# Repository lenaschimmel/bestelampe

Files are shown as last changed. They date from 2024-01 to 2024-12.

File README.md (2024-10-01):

<!--
SPDX-FileCopyrightText: 2024 Lena Schimmel <mail@lenaschimmel.de>
SPDX-License-Identifier: CC-BY-SA-4.0

[besteLampe!](https://lenaschimmel.de/besteLampe!) © 2024 by [Lena Schimmel](mailto:mail@lenaschimmel.de) is licensed under [CC BY-SA 4.0](http://creativecommons.org/licenses/by-sa/4.0/?ref=chooser-v1)
-->

<!-- *Apart from this README, most documentation and notes are in German. If this project becomes more than a proof-of-concept, all important parts the documentation will be translated to English. The name will remain German, as it should be understandable to English speakers as well.* -->

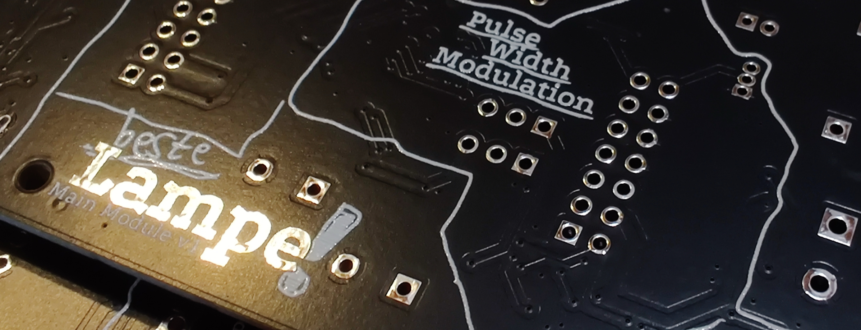
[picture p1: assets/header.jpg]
Header image with PCB closeup


## besteLampe!
**Most lamps suck. This is an open source hardware and software project to create not only a better lamp, but the best lamp(s). Or *"besteLampe(n)!"* as we say in German.**

Of course, there are **many** kinds of lamps, and for some use cases, better alternatives exist. This one is created with two main use cases in mind:
 - indoor lamp for general room lighting and as a sunrise alarm clock 
 - outdoor lamp in front of apartments (called ABL, see below)

The first case involves more direct, manual control of a single lamp, and the second case is more about automatic control (time based, responding to movement, linked with nearby lamps). Anyway, the lamp in each use case will sometimes be operated *just like in the other use case*, so both have mostly the same requirements, just with different priorities.

## Structure of this repository
This project started out with a lot of experimental modules, see [experiments.md](./experiments.md) for information about those.

Current development is focused on the Access Balcony Lamp (ABL), see [hardware/abl](./hardware/abl/) for more information.

Development on indoor lamps may continue once the ABL is finished.

The repository is currently undegoing some restructuring to make it clearer which parts are outdated, active or for future applications.

## What makes ~~a good~~ the best lamp?
These are the design goals of *besteLampe!* 

 - **Free and Open** • open hardware, open software, open protocols
 - **State-of-the-art dimming** • Flicker free, smooth dimming, extremely wide contrast ratio (a.k.a "dim to zero"), independent dimming of color and brightness. (See  ["The problem with driving LEDs with PWM"](https://codeinsecurity.wordpress.com/2023/07/17/the-problem-with-driving-leds-with-pwm/) by Graham to understand what's so hard about that.)
 - **Premium color control** • Use as many color channels as needed to extend the color gamut and achieve good color quality in a reasonable range of colors. (See [the wiki page "Colors"](https://github.com/lenaschimmel/bestelampe/wiki/Colors) for the complexities involved)
 - **Smart, but not smart-ass** • Offers a wide range of wireless connection option, but is also a good, usable device when it's only connection is to the power grid.
 - **Cost efficient** • Should be less expensive than off-the-shelf smart lamps, even if they lack most of its features.
 - **Versatile** • Can be used for many different applications.
 - **Modular** • Provide many features, but not absurdly many, on the base module.
 - **Mains operated, but low voltage DC** • Don't mess with deadly AC.
 - **Power efficiency** • mostly by dimming and switching off.
 - **React to motion and presence** • IR-sensors can only detect motion, so a microwave- or mmwave-sensor must be supported.
 - **Hackable** • Over the air update, flash software and view logs via USB or UART. Pins for future expansions.
 - **Insect friendly** • Reduce the amount of light at night and offer insect friendly spectrum options.
 - **Sleep cycle aware** • Dim lights and avoid blue wavelength at night.
 - **Durable** • Should be usable for decades. Possibility to repair or replace individual parts or modules. Monitor it's own state and send warnings.
 - **Reliable** • Handle outages gracefully, no matter if power outage, network problems or minor component defects.
 - **Fun** • When all the important features are done, add some nice extras. Blinkenlighs-like light shows? UV light? Light based games? Let's do it!

## Not-to-do-list
 - Battery charging, photovoltaic, etc.
 - Addressable LEDs. There is a pin called "Neopixel" but that's not really a design priority, since most addressable LEDs lack in light quality (dimming steps, CRI, flicker)

## License
The besteLampe! is open hardware: 

- The hardware design is licensed under [CERN-OHL-S v2](https://ohwr.org/cern_ohl_s_v2.txt) or any later version.
- The software is licensed under [GNU General Public Licence v3.0](https://creativecommons.org/licenses/by-sa/4.0/legalcode) or later
- The documentation is licensed under [Creative Commons Attribution Share Alike 4.0 International](https://creativecommons.org/licenses/by-sa/4.0/)



See the [license](./license) directory for more details.

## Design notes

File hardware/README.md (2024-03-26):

<!--
SPDX-FileCopyrightText: 2024 Lena Schimmel <mail@lenaschimmel.de>
SPDX-License-Identifier: CC-BY-SA-4.0

[besteLampe!](https://lenaschimmel.de/besteLampe!) © 2024 by [Lena Schimmel](mailto:mail@lenaschimmel.de) is licensed under [CC BY-SA 4.0](http://creativecommons.org/licenses/by-sa/4.0/?ref=chooser-v1)
-->

## Hardware components
 - Hardware
   - **[Main Modules](/hardware/mainmodule/)** • Control board with power supply, micro controller, 6-channel PWM (pulse width modulation) dimmer and many ports.
   - **Extension Modules** • Additional simultaneous wireless protocols, 16 additional PWM channels. Not started yet.
   - **LED Modules** • Stuff that actually emits light. Current focus of hardware development, which might have large impact on the future development of the Main Module as well.
   - **Enclosure** • To hold the electronics together, protect it from the environment, and guide the light.
   - **Reflectors** • Some experiments with 3d-printed reflectors.

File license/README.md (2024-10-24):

<!--
SPDX-FileCopyrightText: 2024 Lena Schimmel <mail@lenaschimmel.de>
SPDX-License-Identifier: CC-BY-SA-4.0

[besteLampe!](https://lenaschimmel.de/besteLampe!) © 2024 by [Lena Schimmel](mailto:mail@lenaschimmel.de) is licensed under [CC BY-SA 4.0](http://creativecommons.org/licenses/by-sa/4.0/?ref=chooser-v1)
-->

## License
The besteLampe! is open hardware and tries to follow the [Best Practices for Open Source Hardware 1.0](https://www.oshwa.org/sharing-best-practices/) from the Open Source Hardware Association (OSHWA).

- The hardware design is licensed under [CERN-OHL-S v2](https://ohwr.org/cern_ohl_s_v2.txt) or any later version.
- The software is licensed under [GNU General Public Licence v3.0](https://creativecommons.org/licenses/by-sa/4.0/legalcode) or later
- The documentation is licensed under [Creative Commons Attribution Share Alike 4.0 International](https://creativecommons.org/licenses/by-sa/4.0/)



All licenses are available in this directory.

## Standard header for hardware design files
### KiCAD
```
(comment 1 "See  https://lenaschimmel.de/besteLampe! for the source and more information")
(comment 2 "This source describes Open Hardware and is licensed under the CERN-OHL-S v2.")
(comment 3 "Copyright 2024 Lena Schimmel <mail@lenaschimmel.de>")
(comment 4 "Design for JLCPCB 1-2 Layer Service")
```

### Others
```
SPDX-FileCopyrightText: 2024 Lena Schimmel <mail@lenaschimmel.de>
SPDX-License-Identifier: CERN-OHL-S-2.0+
This source describes Open Hardware and is licensed under the CERN-OHL-S v2.
You may redistribute and modify this source and make products using it under the terms of the CERN-OHL-S v2 ( https://ohwr.org/cern_ohl_s_v2.txt ).
This source is distributed WITHOUT ANY EXPRESS OR IMPLIED WARRANTY, INCLUDING OF MERCHANTABILITY, SATISFACTORY QUALITY AND FITNESS FOR A PARTICULAR PURPOSE. Please see the CERN-OHL-S v2 for applicable conditions.
Source location: https://lenaschimmel.de/besteLampe!
As per CERN-OHL-S v2 section 4, should You produce hardware based on this source, You must where practicable maintain the Source Location visible on the products you make using this Source, specifially:
 - on at least one printed circuit board inside the product
 - on the external case of the product, if that case is not made in a way that makes it obvious how it can be opened, or if you use practical or legal means to prevent or discourage the user from opening the case, or if the product does not contain a suitable printed circuit board to show the Source Location
```

## Standard header for software source files
```
// SPDX-FileCopyrightText: 2024 Lena Schimmel <mail@lenaschimmel.de>
// SPDX-License-Identifier: CERN-OHL-S-2.0+
// This file is part of besteLampe!.
// 
// besteLampe! is free software: you can redistribute it and/or modify it under the
// terms of the GNU General Public License as published by the Free Software Foundation, 
// either version 3 of the License, or (at your option) any later version.
// 
// besteLampe! is distributed in the hope that it will be useful, but WITHOUT ANY WARRANTY; 
// without even the implied warranty of MERCHANTABILITY or FITNESS FOR A PARTICULAR PURPOSE. 
// See the GNU General Public License for more details.
// 
// You should have received a copy of the GNU General Public License along with besteLampe!.
// If not, see <https://www.gnu.org/licenses/>. 
```

## Standard header for documentation files
```
<!--
SPDX-FileCopyrightText: 2024 Lena Schimmel <mail@lenaschimmel.de>
SPDX-License-Identifier: CC-BY-SA-4.0

[besteLampe!](https://lenaschimmel.de/besteLampe!) © 2024 by [Lena Schimmel](mailto:mail@lenaschimmel.de) is licensed under [CC BY-SA 4.0](http://creativecommons.org/licenses/by-sa/4.0/?ref=chooser-v1)
-->
```

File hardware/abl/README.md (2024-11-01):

<!--
SPDX-FileCopyrightText: 2024 Lena Schimmel <mail@lenaschimmel.de>
SPDX-License-Identifier: CC-BY-SA-4.0

[besteLampe!](https://lenaschimmel.de/besteLampe!) © 2024 by [Lena Schimmel](mailto:mail@lenaschimmel.de) is licensed under [CC BY-SA 4.0](http://creativecommons.org/licenses/by-sa/4.0/?ref=chooser-v1)
-->
## besteLampe! Access Balcony Lamp (ABL)
The Access Balcony Lamp (short ABL, German "Laubengang-Lampe") will be the first device of the besteLampe! series to actually be manufactured.

## Component overview
It consists of these parts:
 - Power Module
   - [Power PCB](./power/)
 - Lamp Module 
   - [LED PCB](./LED_Module_E/)
   - [Controller PCB](./controller/)
 - Connectors between the main PCBs
   - [Rigid connector](./rigid_connector/)
   - [Flex connector](./flex_connector/)
 - Enclosure
   - Not yet online

Additional ressouces:
 - Tools
   - [LED heatplate](./LED_heatplate/)

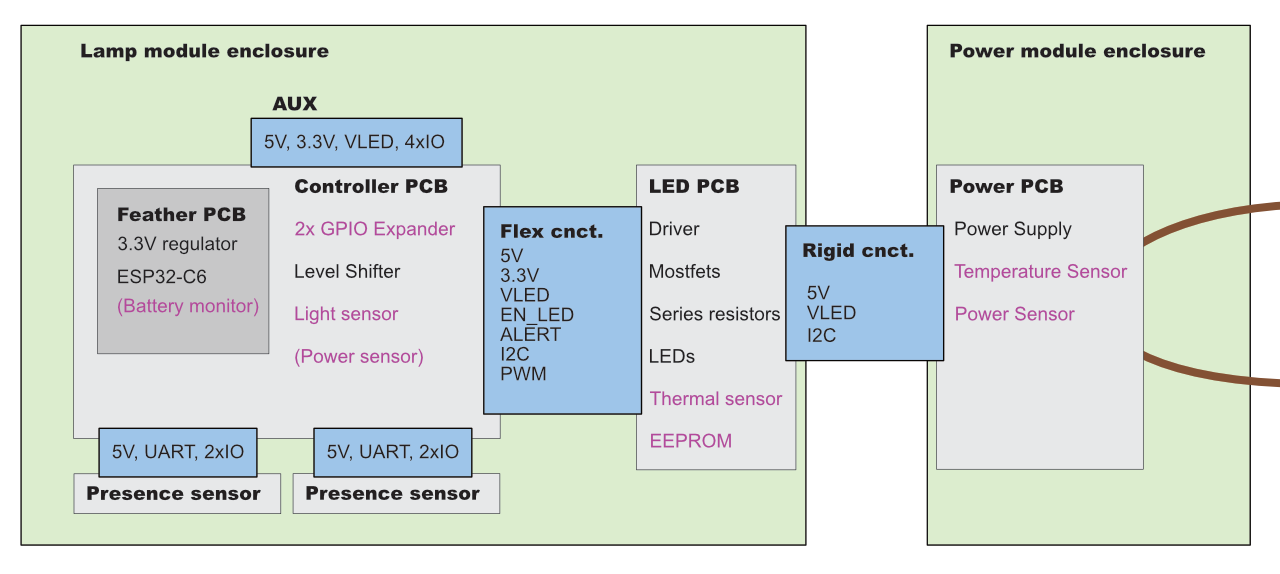
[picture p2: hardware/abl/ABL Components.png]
Simplified diagram of modules and components


## Voltages
The complete system has three or four different voltages / power rails:
 - **230V AC** Input voltage (power modules can be daisy-chained)
 - **5V** Output by the power module and fed through to all other modules. When the controller module is connected via USB-C, it can also source 5V from there and feed it to other components.
 - **3.3V** Supply voltage for several components. The feather module generates this from its 5V input and shares it with most other components. The power module has its own 5V-to-3.3V conversion (which is a bit strange, but probably ok and not worth changing).
 - **VLED** The voltage to drive the LEDs. This is the most significant part of the systems power consumption.

Ideally, the LEDs would be driven with 4V, but since I did not find any power supplies with that voltage, they are currently driven with 5V. For historic reasons, the net `VLED` might still be called `4V` in some places.

Event though the nets `VLED` and `5V` currently carry the same voltage from the same source, they are separate nets in theory. If we manage to find a good 4V power supply, we could create a new power module, and the other modules and connectors should just work with that. The series resistors for the LEDs should probably be replaces as well.

The README for most modules will also have complementing information about available voltages.

## I2C addresses
All modules share a common I2C bus. In the above diagram, the I2C components are highlighted by violet text.

Most devices support multiple addresses, which are selected via address pins. Some of them recognize 4 states per pin: high, low, SDA and SDC. Using static high and low for address selection seems to be more robust.

The INA219 power sensor on the power board serves an additional purpose: the address it reacts to indicates if a 20W or 30W power supply has been installed in the power module.

 - Power Module
    - 64 = 1000000: INA219 (in case of 20W power supply)
    - 65 = 1000001: INA219 (in case of 30W power supply)
    - 82 = 1010010: 24AA025UID (Starting with v1.2, may also trigger 24AA02UID on LED Module v2.0)
    - 79 = 1001111: TMP1075
 - LED Module
    - 75 = 1001011: TMP1075
    - 81 = 1010001: 24AA025UID (Starting with v2.1)
    - 87 = 1010111: 24AA02UID (Will react to any address from 80 to 87, only on v2.0)
 - Controller Module
    - 16 = 0010000: VEML6040
    - 32 = 0100000: TCA6408a (3.3V, starting with v1.1)
    - 33 = 0100001: TCA6408a (5V, starting with v1.1)
    - 67 = 1000011: FLX6408 (3.3V, only in v1.0)
    - 68 = 1000100: FLX6408 (5V, , only in v1.0 - see warning in [controller/README.md](controller/README.md))
    - 69 = 1000101: INA219
 - Feather
    - 54 = 0110110:	Battery monitor (Adafruit ESP-C6)

## Rendering
Artistic rendering showing the inside and outside of the ABL at the same time:

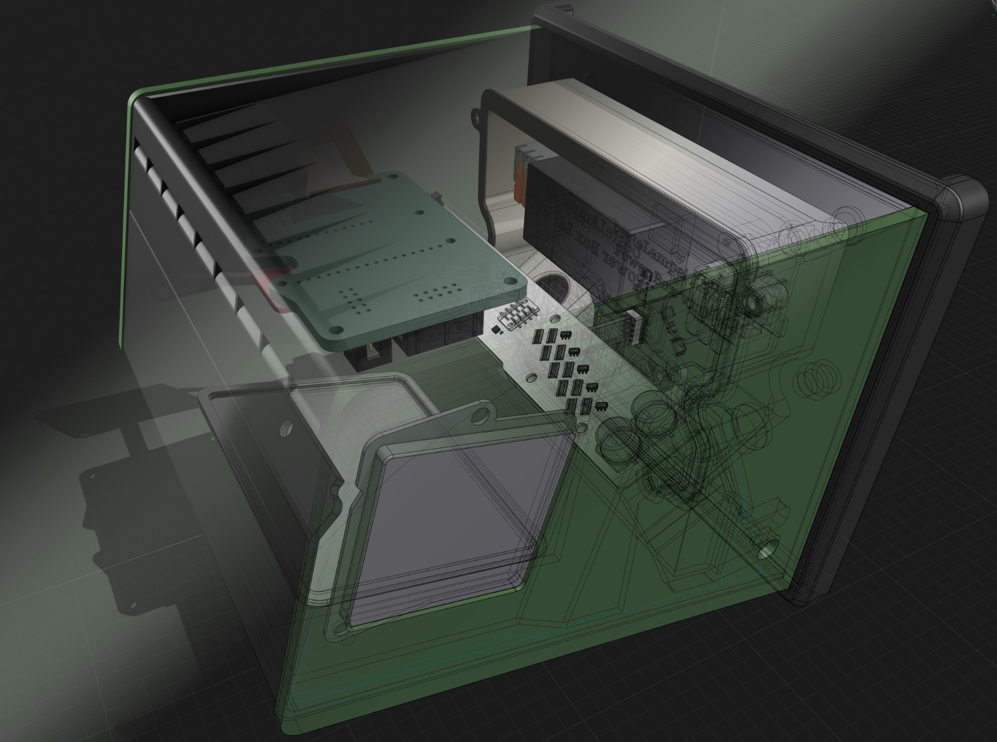
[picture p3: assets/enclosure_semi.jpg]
Image as described above


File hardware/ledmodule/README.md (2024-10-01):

<!--
SPDX-FileCopyrightText: 2024 Lena Schimmel <mail@lenaschimmel.de>
SPDX-License-Identifier: CC-BY-SA-4.0

[besteLampe!](https://lenaschimmel.de/besteLampe!) © 2024 by [Lena Schimmel](mailto:mail@lenaschimmel.de) is licensed under [CC BY-SA 4.0](http://creativecommons.org/licenses/by-sa/4.0/?ref=chooser-v1)
-->

## v1 LED modules
The besteLampe! main module v1 introduced a 14-pin connector for LED modules. 

A very basic module would only have to use two of those Pins: One of the six PWM channel pins, and the 24V pin (5V would also work, but is less efficient in most cases).

More complex modules may have up to six color channels, and may contain one more temperature sensors. They can also contain addressable LEDs, though that is not recommended for the main lighting.

 * Module A and A2 use 6 to 21 mid-power LEDs for each of its six color channels. They are driven with 24V and current-limmiting resistors, so they are directly compatible with Main Module v1.
 * Module B is / was a concept for a slim, quarter-circle module. It's not clear if it will be continued, or made obsolete by Module C.

## Post-v1 modules
Later I experimented a lot with different LEDs, reflectors, lenses, PWM generators, constant-current drivers, etc. These experiments cannot be directly connected to a v1 main module, since they don't have a compatible 14-pin connector.

 * Module C is a testing module for a novel approach with 1 to 3 high-power LEDs per channel, and needs to be driven by a PWM-capable constand-current driver that does not yet exist. Compatibility with Main Module v1 is still unclear. It was mostly tested with low currents (60mA per LED) and worked very vell, but high-current testing is still needed.
 * Module D is a failed attempt. Do not use.
 * Module E is a heavily modified version of Module D, which (hopefully) works better.
     * Module E adaptor, which lets you connect an ESP32-C6-DevKit-C1 to the Module E V1.0 easily
     * Module E was moved to [ABL](../abl/LED_Module_E/) when it was bumped to Version 2.0 and is no longer compatible with the Adaptor.

It's still unclear how the future connector between a main module and LED module(s) will look like...

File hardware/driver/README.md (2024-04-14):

## Driver Modules
Some LEDs are better driven by constant current drivers (CCDs) than by simple MOSFETs and series resistors. See ["Driving LEDs" in the Wiki](https://github.com/lenaschimmel/bestelampe/wiki/Driving-LEDs) for more background on this.

There are multiple Chips which integrate much of the complexity of such drivers, but all of those ICs need specific peripherals around them to actually work. If paired with the correct peripherals, they should work in a very similar way, so that they could be exchanged for one another.

For low-power CCDs like the TLC59711, breakout-boards are available. But for high-power CCDs, no such breakout-boards existed. There were only evaluation-boards, which are 10 times bigger and 10 times more expensive than a breakout-board.

In this directory, I try to add such breakout-boards with a common footprint and pin configuration:

- Driver Module X - an empty template for actual modules
- Driver Module A - for the Allegro A6211

Other drivers that might get a driver module:
- Texas Instruments TPS92200
- Diodes Inc. AL8860
- _If you know similar drivers, let me know!_

I've looked at theses ones as well, but it's unlikely I will make a driver module for them:
- WLMDU9456001JT / 172946001 / MagI3C Power Module (only 450mA and very expesive)
- STM ALED600 (rather expensive and needs many peripherals)

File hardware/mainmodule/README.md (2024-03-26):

<!--
SPDX-FileCopyrightText: 2024 Lena Schimmel <mail@lenaschimmel.de>
SPDX-License-Identifier: CC-BY-SA-4.0

[besteLampe!](https://lenaschimmel.de/besteLampe!) © 2024 by [Lena Schimmel](mailto:mail@lenaschimmel.de) is licensed under [CC BY-SA 4.0](http://creativecommons.org/licenses/by-sa/4.0/?ref=chooser-v1)
-->

# Main module 

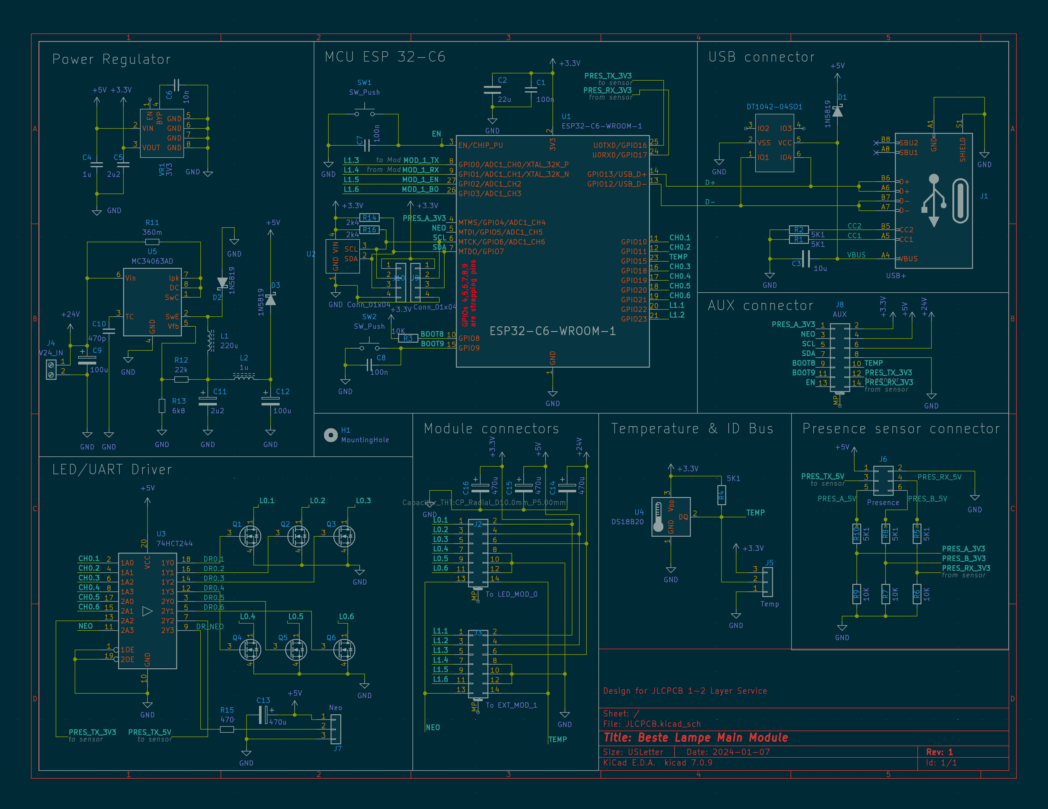
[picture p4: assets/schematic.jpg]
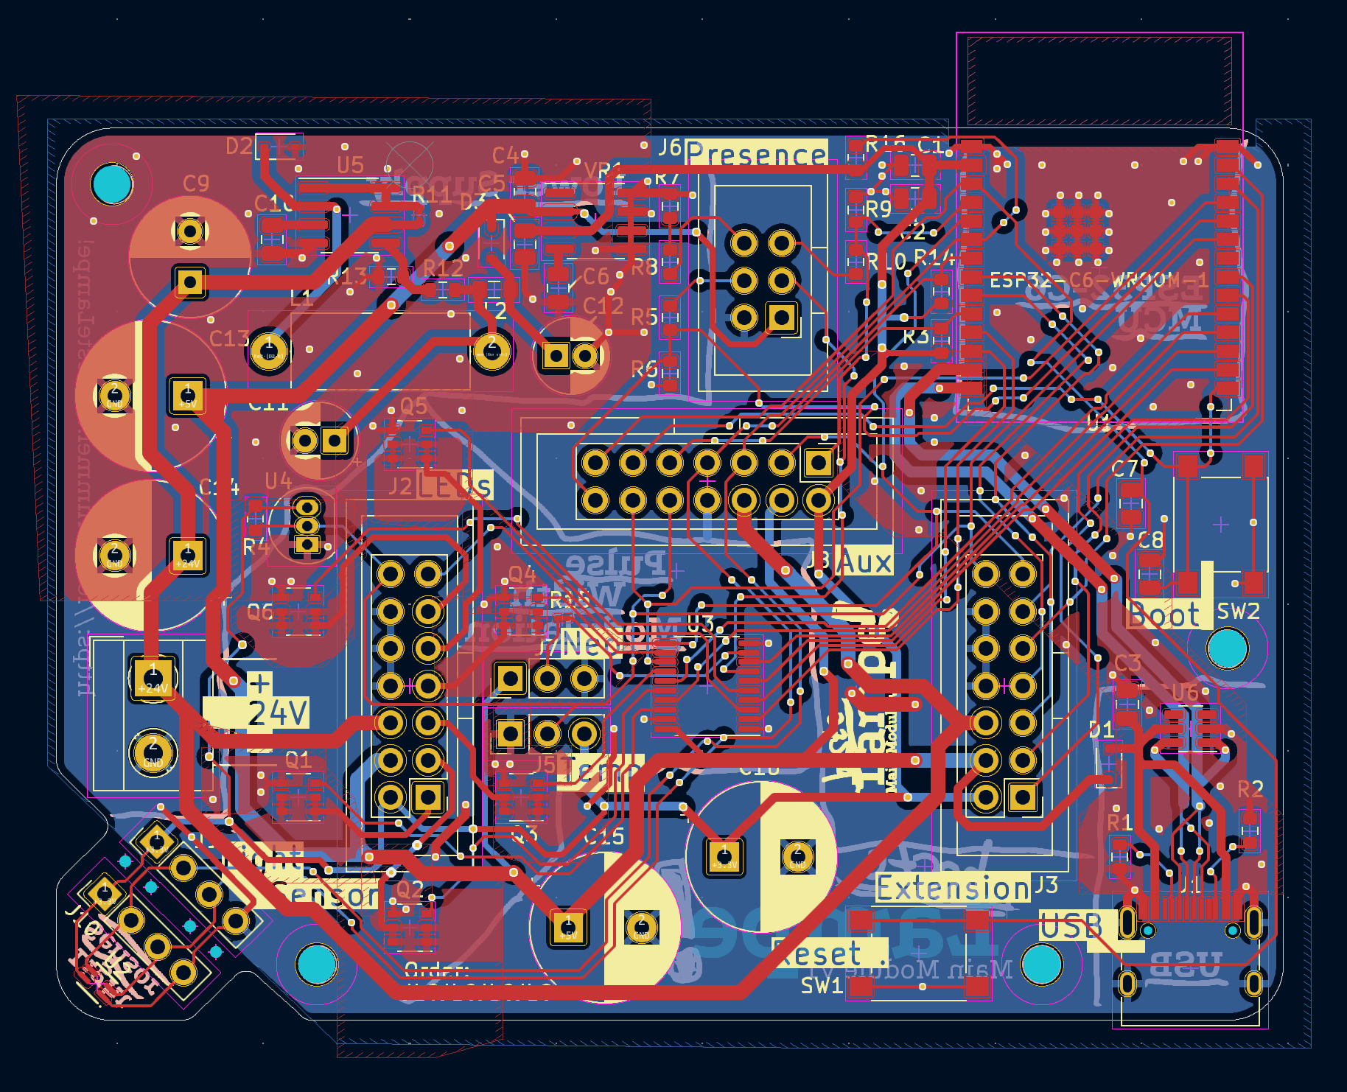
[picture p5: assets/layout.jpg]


## Hardware features / components
- Standard 2-layer PCB
- ESP32-C6 MCU
- Supports four wireless protocols (only one at a time, except Wifi and Bluetooh which can co-exist)
  - Wifi
  - Bluetooth
  - Zigbee
  - Thread
- 6 MOSFET-driven PWM channels with flexible frequency / bit depth
  - e.g. 13 bits = 8192 levels at 5000 Hz
  - or 15 bits = 32,768 levels at 1250 Hz
  - optional 4 bit temporal dithering, increasing the levels by a factor of 16 without reducing the frequency
- Connectors
	- J1: multi-purpose USB-C connector
		- flash new firmware, even when current firmware is broken
		- view logs
		- power the board (Powers everything but LEDs. You may combine USB power and DC power, and switch between both at runtime)
	- J2: LED module. Supports temperature sensor(s) on the LED module.
	    - **Attention: Pins 8, 10 and 12 are GND. In future versions, only pin 12 will remain GND. Pins 8 and 10 will be +24V.**
	- J3: Extension module. Usually contains a secondary MCU and additional LEDs and/or hardware.
	- J4: Power. DC Input 6V to 24V.
		- Must be the same as LED voltage.
		- Generates 5V (buck converter) and 3,3V (linear voltage regulator) for internal and external peripherals.
	- J5: Temp. Attach additional temperature sensor(s) here and/or on the LED module and/or extension module.
	- J6: Presence sensor. Made for seed studio model MR24HPC1, may work with others.
	    - Provided 5V power to the sensor.
		- TX is shifted up from 3,3V to 5V
		- RX, A and B are shifted down form 5V to 3,3V
		- B is not connected to the MCU
	- J7: Neopixel. You can connect addressable LEDs here. Only 5V supported on this connector. Modules on J2 and J3 also get the control signal, and get 24V to power LEDs.
	- J8: AUX. Used for debugging, testing, etc.
	- J9 and J10: Light sensor. The VEML6040 sensor is directly connected on the PCB, but you could break off or cut off the part with the sensor and use these pins to connect it over wire.
- 1-wire bus for temperature sensors and other devices
	- onboard 12 bit temperature sensor between Mosfet and capacitors
	- bus is also connected to J2, J3, J5 and J8

## Cost
I've ordered 10 PCBs from JLCPCB, with SMD components included and soldered, but without any through-hole components. I payed about 100 Euro incl. tax and shipping, so around 10 Euros per PCB. This does not include the ESP32-C6 (3.60 Euro) because they didn't have it in stock, nor the VEML6040 Light sensor (0.90 Euro) because I forgot to place it. So the actual price would be 14.50 Euro per board.

When ordering 100 pieces, and with some very minor tweaks in v1.1 to reduce the assembly fees, price per PCB incl. SMD assembly will drop to 8.10 Euro incl. ESP and light sensor.

The through hole components are 4.30 Euro per board and will drop top 2.70 for v1.1.

So the full v1.1 board will be around 10.80 Euro.

## Known problems for v1
_Should be converted into issues soon, but it's quicker to just list them here._

### High severity
_No known fix_

* The inductor of the 5V buck converter makes an audible noise, especially when the presence sensor is connected

### Medium severity
_Prevent the board from working, but can easily be fixed manually_

* Wrong footprint for R11 and R15, so they are not assembled. Because they are not really needed, you can bridge them with a drop of solder.
* Pin 1 of VR1 (Enable of the 3.3V voltage regulator) needs to be connected to 5V. You can place a very short wire or even a drop of of solder over to Pin 2.
* Pin 3 of the ESP (Enable) module needs a pull up resistor. You can hand-solder one to the bottom of J8, or instead of J8 if you don't need the connector.
* Light sensor is no placed, and it's unknown if it would work if placed

### Low severiy
_Would be nice to fix these, but it's ok as it is_

* The antenna of the ESP extends over the rectangular board footprint. That was a deliberate design choice, but I regret it.
* Mounting holes are too small for M3 screws.
* An additional mounting hole at the top right would be nice.
* USB data lines are length-matched and work just fine (it's just USB 2.0), but violate many rules:
   * not impedance-controlled (I tried, but used totally wrong numbers)
   * opposite ground plane is not continous
   * four vias when it could be done with zero or two
* Thick wires have tiny vias
* Net `Pres_B` of the presence sensor is shifted down to 3.3V but not connected to the ESP or anything else
* Would be nice to have some small LEDs on board
	* Power LEDs that light up as long as there is 24V, 5V and 3,3V (should be very dim)
	* 1 LED per PWM channel to test it without an LED module attached (common +24V could be switched with a jumper)
* It would also be nice to support USB Power Delivery, so that the LEDs could light up when only USB is connected, for easier development. PD does not support 24V, only 20V, but the LEDs that I tested are ok with that.
* use an SMD version of the temperature sensor because it's much cheaper

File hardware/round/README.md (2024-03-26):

<!--
SPDX-FileCopyrightText: 2024 Lena Schimmel <mail@lenaschimmel.de>
SPDX-License-Identifier: CC-BY-SA-4.0

[besteLampe!](https://lenaschimmel.de/besteLampe!) © 2024 by [Lena Schimmel](mailto:mail@lenaschimmel.de) is licensed under [CC BY-SA 4.0](http://creativecommons.org/licenses/by-sa/4.0/?ref=chooser-v1)
-->

## Round lamp enclosure
This is a prototype of a round, wall-mounted lamp enclosure, based on a cheap transparent flower pot I found at the local hardware store.

It's intended for an *extended setup* (see [the "Price" section in the main readme](/README.md#price)), so it will have four groups of six color channels. That makes it possible to control the brightness and color for each direction separately. The current iteration prioritizes the diffusor for very smooth transitions between the four sections, and the light emission is undirected.

Instead of LED modules with custom PCBs, I'm using short LED strips which can be bent in one dimension only.

There is also a short ring of addressable LEDs that illuminate the front plate. You can insert a mask here to display e.g. a house number, short word or small graphic, and tint it in colorful animated gradients.

**Everything in this directory is very messy and work in progress - you are not (yet) suppose to understand the files and how to assemble this lamp.**

## Principle and Prototype
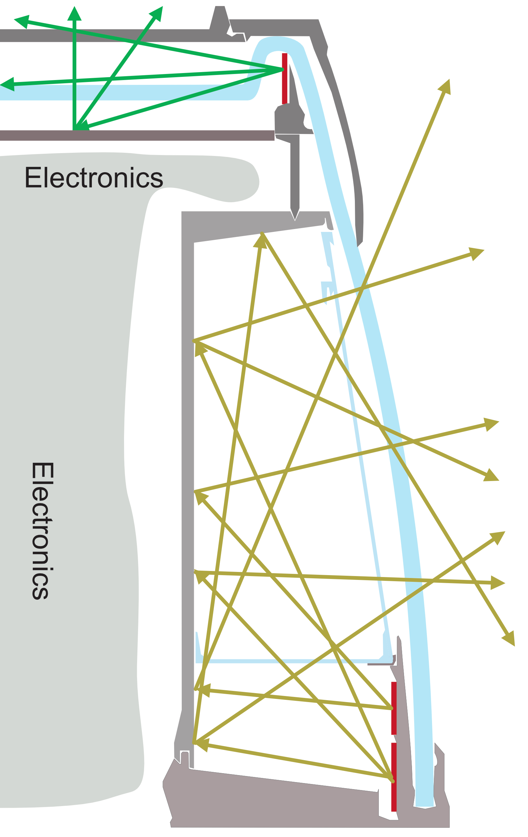
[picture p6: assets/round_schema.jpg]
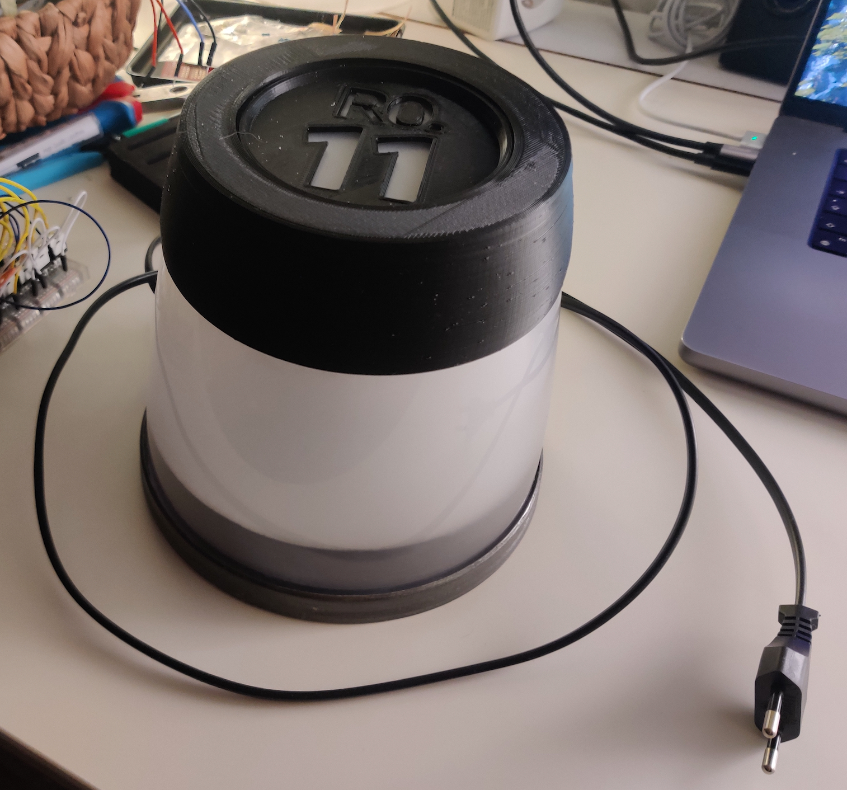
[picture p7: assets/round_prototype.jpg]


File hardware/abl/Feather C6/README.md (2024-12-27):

## Adaptation of Adafruit ESP32-C6 Feather - STEMMA QT PCB
### Adaptation
This PCB design is based on the [Adafruit ESP32-C6 Feather - STEMMA QT PCB](https://github.com/adafruit/Adafruit-ESP32-C6-Feather-PCB).

At the beginning, it was only a port of the EagleCAD schematic and board layout to KiCad.

With time, it will deviate further from the original design, with these primary development goals:
 - [x] Better signal integrity and EMI, by using:
   - [x] Proper ground planes, using 4 instead of 2 layers
   - [x] More ground pins
 - [ ] Reduced production cost by removing some components
   - [ ] LiPo battery charger / monitor and connector
   - [ ] NeoPixel
 - [ ] Changes to the power pins to better support different directions of power distribution (from USB to Wing, or from the Wing)

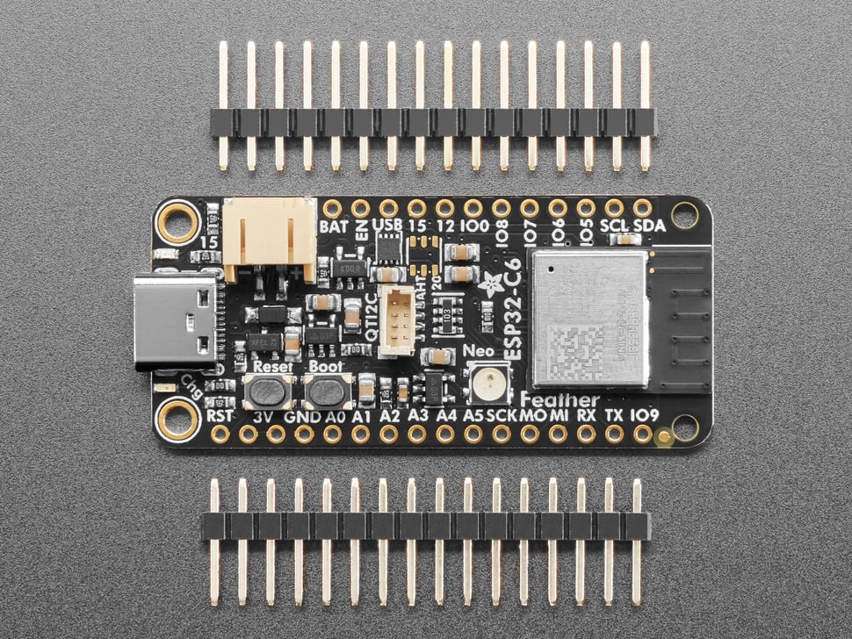
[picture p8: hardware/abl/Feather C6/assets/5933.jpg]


See the [original Version in the Adafruit shop](https://www.adafruit.com/product/5933)

### Description
_Unchanged from the original repository_

The ESP32-C6 is Espressif’s first Wi-Fi 6 SoC integrating 2.4 GHz Wi-Fi 6, Bluetooth 5 (LE) and the 802.15.4 protocol. It brings the goodness you know from the low-cost C3 series and improves it with Zigbee/802.15.4 at 2.4Ghz. That means it could make for great Matter development hardware!

We took our Feather ESP32-S2 and swapped out the 'S2 for a C6. Plus some re-routing and here's what we've got: a C6 Feather with lots of GPIO, lipoly charging and monitoring with the MAX17048, NeoPixel, I2C Stemma QT port, and a second low-quiescent LDO for disabling the I2C and NeoPixel when we want ultra-low power usage - as low as 17uA in deep sleep.

One thing to watch for is that, like the C3, the C6 does not have native USB. It does have a 'built in' USB Serial core that can be used for debugging, but it cannot act like a mouse, keyboard, or disk drive. That means if you are running CircuitPython you will need to use WiFi, Bluetooth or WebSerial for transferring files back and forth rather than drag-and-dropping to a drive. Ditto for the bootloader side, this chip cannot run UF2.

Another thing to be aware of, is  the ESP32-C6 does not have as many GPIO as the ESP32-S2 or ESP32-S3, so A2 is the same GPIO pin as IO6 and A3 is the same pin as IO5. However, this gives it the most compatibility with our existing FeatherWings.

### included components (BOM)
| Part Name | Designator | Count  |
|---|---|---|
| KH-2.54FH-1X16P-H8.5  | JP1 | 1 |
| CL21A106KAYNNNE | C1,C2,C6,C7,C8,C9  | 7 |
| 0603WAF5101T5E | R1,R10,R5,R8 | 5 |
| SK34WA | D4 | 1 |
| IN-S63AT5UW | D3 | 1 |
| KH-2.54FH-1X10P-H8.5  | J1,J2 | 2 |
| KH-2.54FH-1X12P-H8.5  | JP3 | 1 |
| KMR211NGLFS | SW1,SW2 | 2 |
| AP2112K-3.3TRG1 | U2 | 1 |
| CL10A105KB8NNNC | C10,C4 | 3 |
| ESP32-C6-MINI-1-N4 | U1 | 1 |
| 0603WAF1003T5E | R12,R6,R7 | 4 |
| USB-TYPE-C-019 | X3 | 1 |
| DMG3415U | Q3 | 1 |

### License
Adafruit invests time and resources providing this open source design, please support Adafruit and open-source hardware by purchasing products from [Adafruit](https://www.adafruit.com)!

Designed by Limor Fried/Ladyada for Adafruit Industries.

Adapted by Lena Schimmel.

Creative Commons Attribution/Share-Alike, all text above must be included in any redistribution. 
See license.txt for additional details.

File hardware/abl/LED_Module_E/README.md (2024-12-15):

<!--
SPDX-FileCopyrightText: 2024 Lena Schimmel <mail@lenaschimmel.de>
SPDX-License-Identifier: CC-BY-SA-4.0

[besteLampe!](https://lenaschimmel.de/besteLampe!) © 2024 by [Lena Schimmel](mailto:mail@lenaschimmel.de) is licensed under [CC BY-SA 4.0](http://creativecommons.org/licenses/by-sa/4.0/?ref=chooser-v1)
-->

## LED Module E + G
The former LED Module E has been split into two separate PCBs:
 - Module E (classic 4--layer PCB with driver logic, MOSFETs and series resistor)
 - Module G (1-layer copper-core PCB with actual LEDs and temperature sensor)

In conjuction, they feature 10 small, high-powered Cree XLamp Element LEDs places close to one another along an edge, and some of the electronics needed to power them.

The split into separate PCBs is very recent, and the files have not yet been completely reorganized. Module G is still in this directory, and its files are still named "LED_Module_E_copper". They will move into their own directory soon.

### Parts on Module E
| Reference | Value | Datasheet | Footprint | Qty  | DNP  | Manufacturer_Part_Number  | LCSC Part #  | Purpose |
|---|---|---|---|---|---|---|---|---|
| C1,C2,C3 | 100nF | ~ | Capacitor_SMD:C_0402_1005Metric | 3 | | CL05B104KO5NNNC | C1525 | Decoupling capacitor |
| C4,C5 | 1000uF | ~ | Capacitor_SMD:CP_Elec_10x7.9 | 2 | | VKME1301C102MV | C487313 | Bulk capacitor |
| J1 | SFW20S-2STE1LF | https://cdn.amphenol-cs.com/media/wysiwyg/files/drawing/10172832.pdf | Own footprints:SFW20S2STE1LF_Own | 1 | | SFW20S-2STE1LF | C3168412 | Flex cable connector |
| J3 | 9159008603906 | https://datasheets.kyocera-avx.com/9159-600.pdf | 9159008603906 | 1 | | 9159008603906 | C22394454 | Rigid board connector |
| Q1,Q2,Q3,Q4,Q5,Q6,Q7,Q8,Q11,Q12 | Si3456DDV | https://www.vishay.com/docs/69075/si3456ddv.pdf | Package_SO:TSOP-6_1.65x3.05mm_P0.95mm  | 10 | | SI3456DDV-T1-BE3 | C6295864 | MOSFET transistor |
| R1,R2,R3,R4,R5,R6,R7,R8,R9,R10,R11,R12,R13,R14,R15,R16,R17,R18,R19,R20  | 200mR | ~ | Resistor_SMD:R_1020_2550Metric | 20 | | RCWE1020R200FKEA | C4000899 | Series resistor |
| R21,R22,R23,R24,R25,R26,R27,R28,R31,R32,R33,R34,R35,R36,R37,R38 | 4700R | ~ | Resistor_SMD:R_0402_1005Metric | 16 | | 0402WGF4701TCE | C25900 | Pullup resistor |
| R40,R41 | 2740R | ~ | Resistor_SMD:R_0603_1608Metric | 2 | | 0603WAF2701T5E | C13167 | Pullup resistor |
| U2 | 74HC245 | http://www.ti.com/lit/gpn/sn74HC245 | Package_SO:TSSOP-20_4.4x6.5mm_P0.65mm  | 1 | | SN74AHCT245PWR | C10910 | Bus transceivers / line driver  |
| U3 | 24AA025E48T-I/OT  | https://www.lcsc.com/datasheet/lcsc_datasheet_1810121540_Microchip-Tech-24AA025E48T-I-OT_C129895.pdf  | Package_TO_SOT_SMD:SOT-23-6 | 1 | | 24AA025E48T-I/OT | C129895 | EEPROM |
| U4 | 74LVC1G32 | http://www.ti.com/lit/sg/scyt129e/scyt129e.pdf | Package_TO_SOT_SMD:SOT-353_SC-70-5 | 1 | | 74LVC1G32SE | C460530 | Logic OR gate |

### Parts on Module G
This module only contains the 10 LEDs and a temperature sensor:
 - 10x CREE XLamp Element G in 8 different colors ([Datasheet](https://www.mouser.de/pdfDocs/XLamp-XE-G.pdf))
 - 1x TMP1075 Temperature sensor ([Datasheet](https://www.ti.com/lit/ds/symlink/tmp1075.pdf))

### Relation to previous LED modules
Version 1 of this module was partly based on the failed [LED Module D](../../ledmodule/LED_Module_D/), but with a lot of changes:

 - larger board
 - re-assinged all components to the three power rails
 - removed the TLC59711 as PWM generator
 - instead 8 separate inputs for PWM signals
 - two of the input signals are duplicated to power 2 LEDs each (but with separate MOSFETs and resistors)
 - more and larger mounting holes
 - improved thermal conductance (more thermal vias, etc.)
 - optimized traces
 - optional pull-ups for the I2C bus
 - solder jumper to directly tie the alert signal of the temperature sensor to the enable input of the driver
 - added test pads
 - added bulk capacitor
 - switched to 100% SMD parts
 - LED voltage can be supplied via USB-C or via two pins of the Pin header (see below)

It was a bit larger than LED module D, but the placement of the LEDs was still the same, which proved to be a good fit for the linear half-bown reflector prototype.

Now this is version 2, which has a very different form factor. It's much larger, and the LED are on the long side instead of the short one.

### VLED
With single LEDs (parallel, in contrast to series / strings), a voltage around 4V would be a good choice for the supply voltage, so that the series resistors don't waste too much energy.

But it's surprisingly difficult to find a good source for 4V if you've got only 230V AC, 5V and 3.3V DC to work with. It seems much more straight-forward to use 5V and adjust the series resistors to it.

The CD74HCT244 needs 4.5 V to 5.5 V to operate, so it already had a 5V rail. The power rail for the LEDs was historically called 4V, and even though it's lablled `VLED` on the silkscreen now, the nets are still called 4V in Kicad. Both rails are still separate, just in case I'll find a good 4V source in the near future.

### Temperature Alert
Usually, the MCU should monitor the temperature via the TMP1075 sensor, and reduce the LED power before they get too hot. Via I2C, the MCU can read the excact temperature value.

The MCU can also set an alert threshold on the sensor, so that it will trigger its ALERT pin when the LEDs get too hot.

As an extra safety measure, the ALERT net can be linked directly to the ENABLE net via the solder jumper JP1. If the MCU has crashed, or for some other reason is not able to react to the rising temperature, this should turn off the LEDs without the MCUs intervention. This feature is untested, and the jumper is open by default.

### EEPROM addressing issue
Version 2.0 of the LED board contained an 24AA02UID, which will react to any address from 80 to 87. This prevents the usage of multiple EEPROMs on one bus. Newer versions of the LED Module and Power Module use individually addressable 24AA02**5**UID (note the slightly different part number). In software, you should first check if an EEPROM on address on 87 is present. If yes, it's on the LED Module and you can't detect / use an EEPROM on the Power Module. If no, there *should* be an EEPROM at 81 on the LED Module, and there *could* be another on on 82 on the Power module.

### Rendering
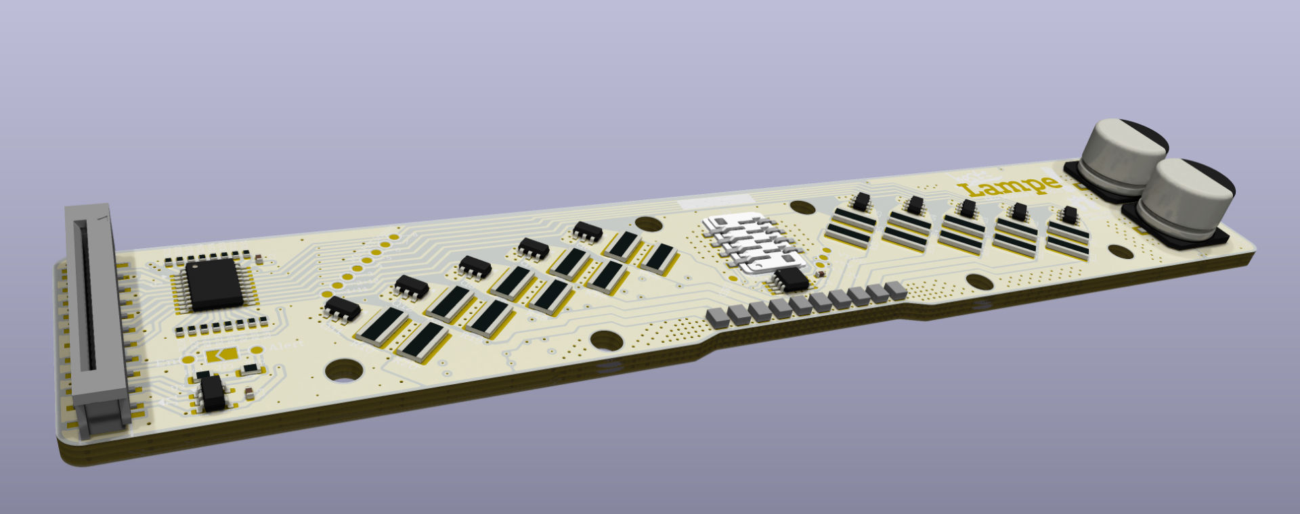
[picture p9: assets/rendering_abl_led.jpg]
KiCad rendering of the PCB, as of 2024-10-24


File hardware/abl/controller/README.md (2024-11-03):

<!--
SPDX-FileCopyrightText: 2024 Lena Schimmel <mail@lenaschimmel.de>
SPDX-License-Identifier: CC-BY-SA-4.0

[besteLampe!](https://lenaschimmel.de/besteLampe!) © 2024 by [Lena Schimmel](mailto:mail@lenaschimmel.de) is licensed under [CC BY-SA 4.0](http://creativecommons.org/licenses/by-sa/4.0/?ref=chooser-v1)
-->
## ABL Controller Module
This module started out as a simple passive adapter to connect an ESP32-C6 to the LED Module and power module, but has become more complex by now.

It contains an RGB light sensor and connects to:
 - up to two human presence sensors
 - optional expansions via
   - I2C (Quiic / Stemma QT connector)
   - additional GPIOs

### Feather MCUs
The socket for the MCU has the [Adafruit Feather](https://learn.adafruit.com/adafruit-feather/overview) formfactor. There are at least three different implementations of the ESP32-C6 in this formfactor, as well as dozens of other MCUs.

The feather spec is strict enough that every kind of Feather *should* be safe to plug in, e.g. fits mechanically and will not damage itself or other modules. The specific pin assignments of feathers are different though, and care has been taken to use the pins in a way that is at least compatible with all three ESP32-C6 feathers:

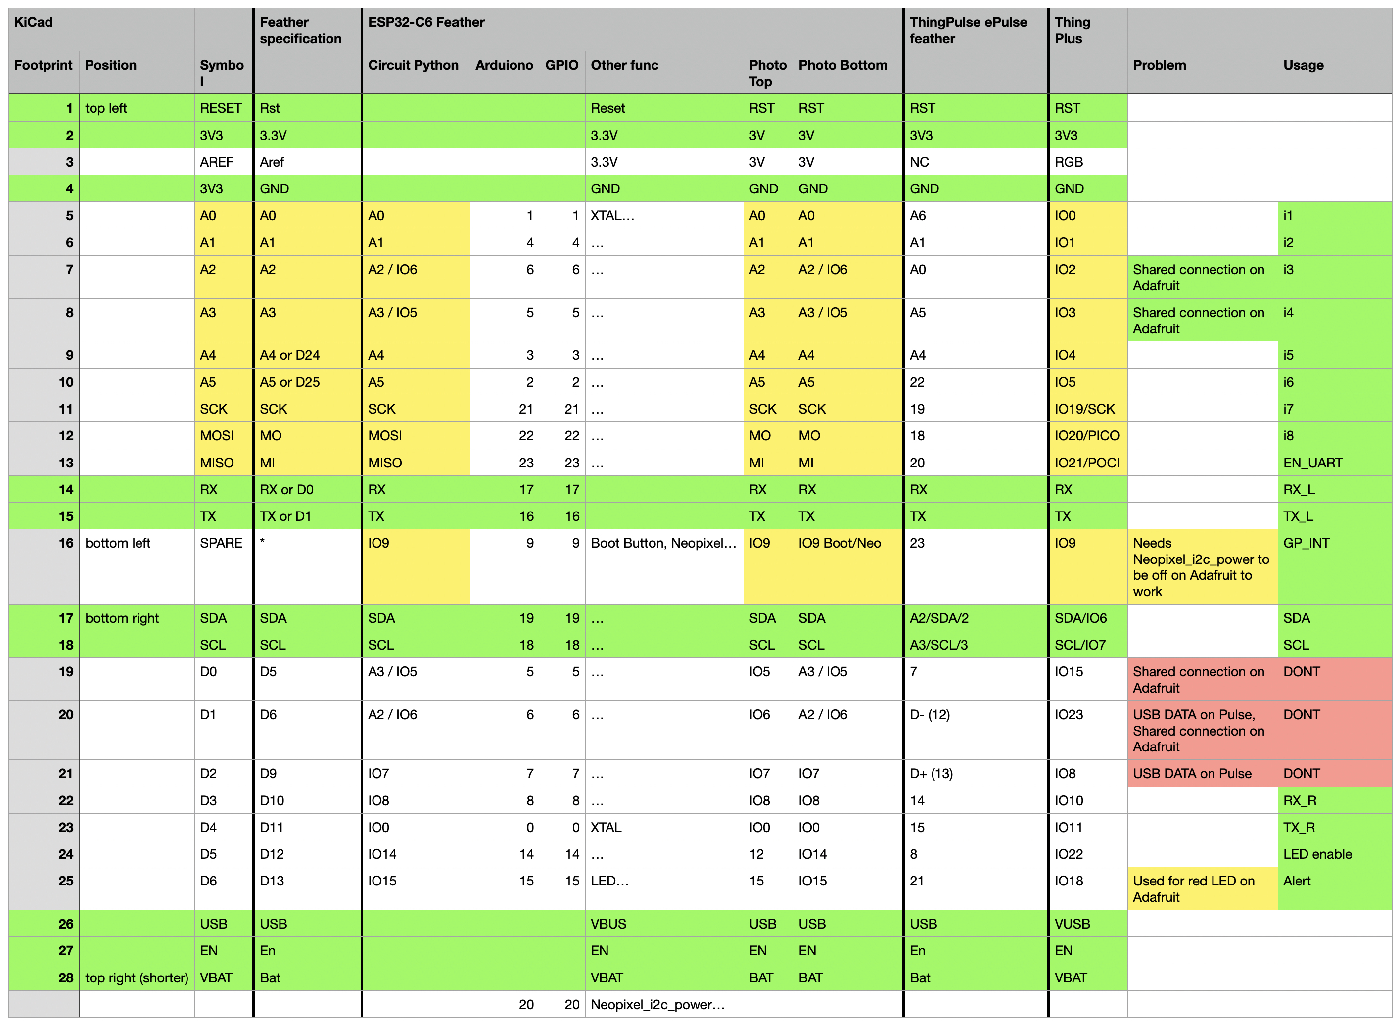
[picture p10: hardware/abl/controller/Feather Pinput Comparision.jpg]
Table of pinouts and problems for three ESP32-C6 implementations


**WARNING:** The above table displays the pinout for controller v1.0 but 13 and 16 changed in v1.1 - there will be an updated table later.

Obviously, the software must use specific pin assignments for each of the three feathers, and since it's not possible to detect the kind of feather at runtime, the software must be purpose-build for a specific feather.

### GPIOs
As shown in the table above, the GPIO pins can be referenced by several different names and numbers. It's recommended to use the pad number (leftmost column) or net name (rightmost column) to talk about a specific GPIO pin.

The feather does not offer enough GPIO pins for all current (and future) features, so the module contains two GPIO expanders with 8 GPIOs each. One of them is running on 3.3V logic, and its ports are called `FX_3_0` to  `FX_3_7`. The other one is running on 5V logic and has pins `FX_5_0` to  `FX_5_7`.

### Presence sensors
Up to two presence sensors can be connected to the controller (left and right).

Many different types of presence sensors shall be supported. They all communicate via UART (and 0 to 2 additional logic pins), but can have different voltage requirements:
 - 5V for power and logic
 - 5V for power, but 3.3V for logic

For this reason, both connectors each carry:
 - Ground
 - 5V supply (switched)
 - UART (RX + TX) at 3.3V
 - UART (RX + TX) at 5V
 - 2x GPIO at 3.3V
 - 2x GPIO at 5V

**WARNING:** In v1.0, I have uses `FXL6408` GPIO extenders because of availablity, but it only supports voltages up to 4.0V. One of the two chips is currently running on 5V which is not safe. Starting from version 1.1 a TCA6408ARSVR is used instead.

The left and right presence connector are independant: each has its own UART, its own GPIO pins, and the supply power for each one can be switched independantly. So you could connect two completely different sensors.

For a single presence connector, the UART pins are redundant: the 5V UART is just a logic-shifted version of the 3.3V UART. But the two 3.3V GPIOs are separate form the two 5V GPIO pins, e.g. four independant signals.

**Caveat:** The ESP32-C6 has three UARTs, but only one of them (UART1) can be used freely. UART0 is somehow used for the debugging console, but it seems that it can be used for sensors as well, if the console only needs TX and the sensor only needs RX. There is an even better workaround: use the RMT peripherals to emulate up to two UARTs.

The power of the presence sensors can be switched for these reasons:
 - Each presence sensor contains its own MCU, and if it should hang/crash, we can reset it by power-cycling.
 - An advanced presence sensor can consume up to 1W continously, so we want to switch them off during the daylight to save energy.
 - To prevent interference between the two sensors in a lamp, but also with sensors from other nearby ABLs, we may need to use the sensors in turns. Some models can't be (de-)activated via UART, so we must cut their power instead.

### Other power and voltage considerations
The controller board does not directly deal with `VLED`, since it only outputs the PWM signals on 3.3V logic level.

But during testing / debugging, the controller module can be powered over USB-C. Then it will provide 5V and 3.3V to the other modules. VLED is also connected directly to 5V, unless you cut the solder jumper JP1.

When powered via USB-C, there is at most 15W available in total, compared to 20W or 30W from the power module. When the power module is disconnected, it cannot measure the current, and even if it was connected, the current from USB / VBUS does not flow through shunt resistor of the INA219 on the power module. For this reason, it is possible to place a second INA219 and shunt resistor directly onto the controller. For normal operation, this is not needed.

### Light sensor
This sensor is intended to monitor the overall light output of the LED module. The (up to) 8 different colors / spectra are mixed inside the lamp enclosure, which will be shaped to diffusely reflect the light mix onto the sensor. When all LEDs are off, the sensor might also be used to detect external (day-)light, but this is not its primary purpose.

### Additional connectors
The AUX connector (J5) and STEMMA QT / Qwiic connector (J4) can be used for debugging and/or future extensions. Both provice 3.3V supply voltage and I2C at 3.3V. The AUX connector also has VLED, 5V and four GPIOs (two at 3.3V and two at 5V).

### Rendering
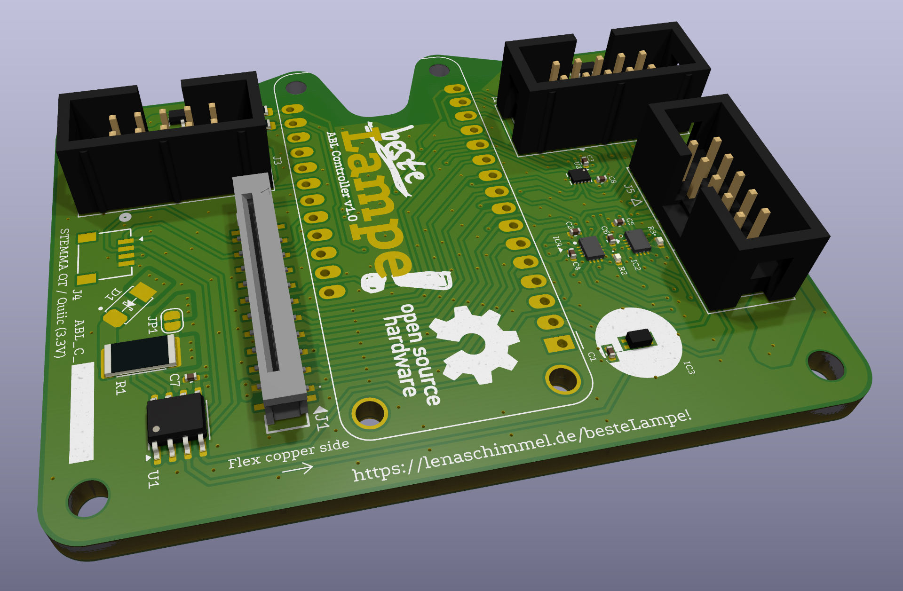
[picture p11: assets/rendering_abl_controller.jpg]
KiCad rendering of the PCB, as of 2024-10-24


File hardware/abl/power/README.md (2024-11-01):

<!--
SPDX-FileCopyrightText: 2024 Lena Schimmel <mail@lenaschimmel.de>
SPDX-License-Identifier: CC-BY-SA-4.0

[besteLampe!](https://lenaschimmel.de/besteLampe!) © 2024 by [Lena Schimmel](mailto:mail@lenaschimmel.de) is licensed under [CC BY-SA 4.0](http://creativecommons.org/licenses/by-sa/4.0/?ref=chooser-v1)
-->
## ABL Power Module
This module contains:
- two sets of 230V terminals with PE
- 20W or 30W power supply (PS)
- temperature sensor
- power sensor (voltage and current)
- status LED
- resettable fuse / polyfuse / overheating protection
- inrush current limiter
- EEPROM

The power module does not monitor its own sensors. The controller module should do this, and drive the LEDs in a way that does not exceed the current and temperature limits of the PS. The polyfuse also acts as a overheating protection, disconnecting the 230V AC at about 100°C. It may take several minutes to fully reset the fuse, so this should still be prevented by derating in software.

Many power modules can be daisy-chained using the two sets of 230V terminals. The fuse and inrush current limiter only apply to the local power supply, not the whole chain.

The power module has its own 3.3V buck converter. It does neither supply 3.3V to the other modules, nor does it receive 3.3V from them.

You can solder in either a 20W or 30W PS. You must bridge two pads of the solder jumper to indicate which PS is present. This affects the I2C address of the power sensor, which allows us to communicate this bit of information to the controller without an extra wire. For the specific I2C addresses of the sensors, see the README in the [parent directory](../README.md).

Ground and PE are separate, but could be connected by placing the resistor R5. I've extrapolated from [this toot/thread about USB grounding](https://mastodon.social/@tubetime/113036756672478830) that it might be a good idea.

### Rendering
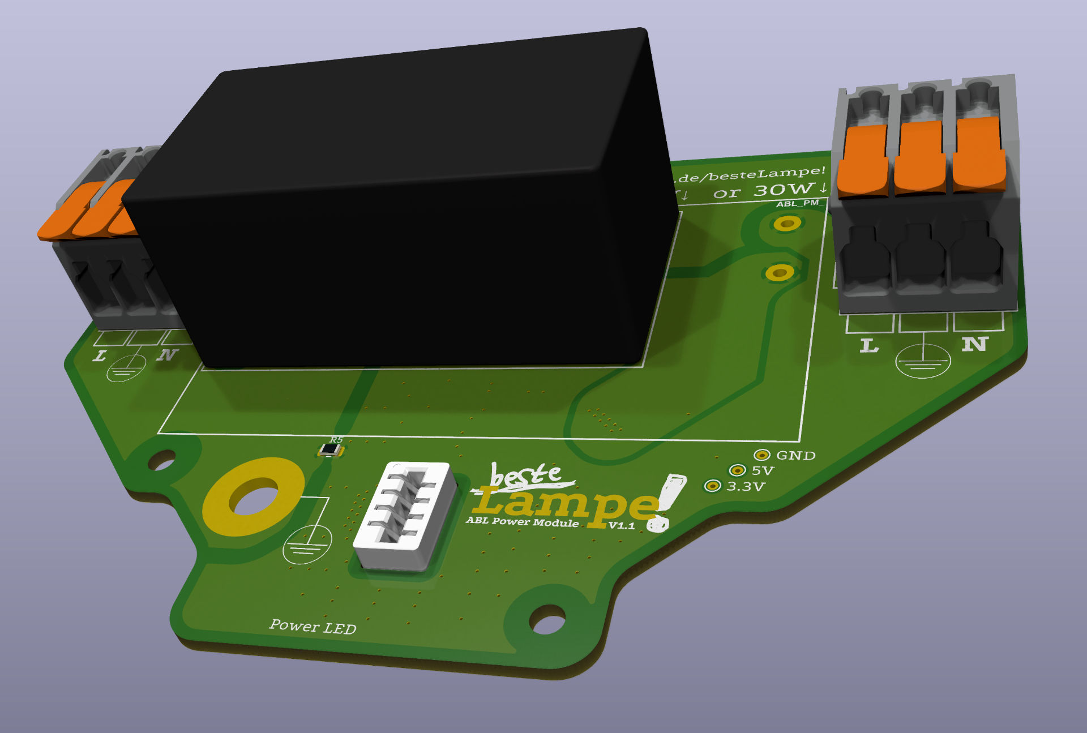
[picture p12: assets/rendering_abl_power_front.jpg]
KiCad rendering of the PCB, as of 2024-10-24

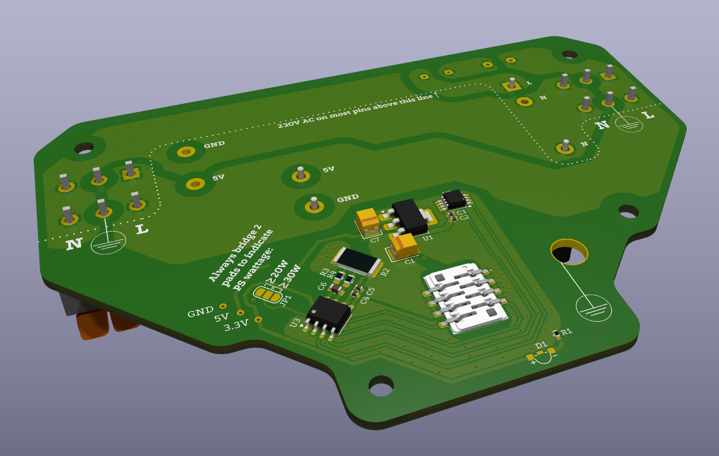
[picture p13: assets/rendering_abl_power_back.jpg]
KiCad rendering of the PCB, as of 2024-10-24


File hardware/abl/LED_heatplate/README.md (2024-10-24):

<!--
SPDX-FileCopyrightText: 2024 Lena Schimmel <mail@lenaschimmel.de>
SPDX-License-Identifier: CC-BY-SA-4.0

[besteLampe!](https://lenaschimmel.de/besteLampe!) © 2024 by [Lena Schimmel](mailto:mail@lenaschimmel.de) is licensed under [CC BY-SA 4.0](http://creativecommons.org/licenses/by-sa/4.0/?ref=chooser-v1)
-->
## ABL LED Heatplate
This PCB is a tool to facilitate soldering the [LED Module E](../LED_Module_E/). On an internal layer, it has three long resistive traces that can heat up three areas of the top side. A regular heatplate can't be used because of the central "Dual Row Inverted Thru Board Card Edge Connector".

The resistence, recommended voltage and power of this heatplate are currently unknown. I expect this to be working with 5V, but I'll have to measure once it arrives.

I will add recommendations for assembly as well.

### Rendering
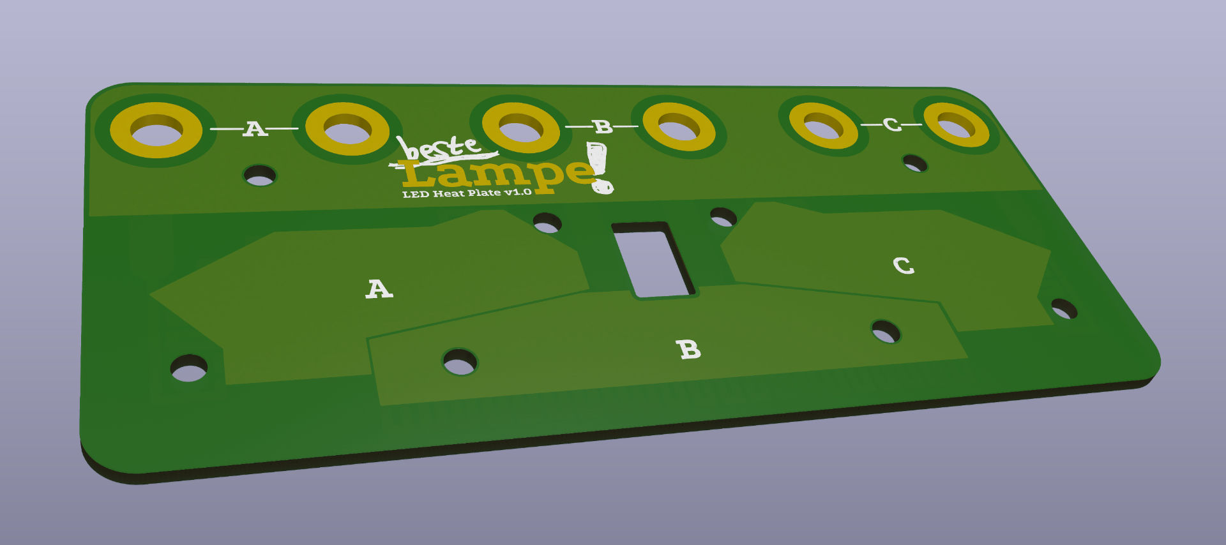
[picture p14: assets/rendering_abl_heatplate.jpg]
KiCad rendering of the PCB, as of 2024-10-24


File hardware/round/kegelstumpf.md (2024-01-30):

M = 72,9mm 
m = 36,1mm
R = 71,4mm Radius Grund
r = 36,0mm Radius Mantel
h =  7,2mm Höhe

a = 360°*R/M = 352,6°

M=63,6 ~ 127,2
m=37,1 ~  74,2

## Hauptdiffusor
R = 73,0mm
m = 91,6mm
r = 63,0mm
h = 92,0mm
x = 10,0mm

=> M = 668,7mm

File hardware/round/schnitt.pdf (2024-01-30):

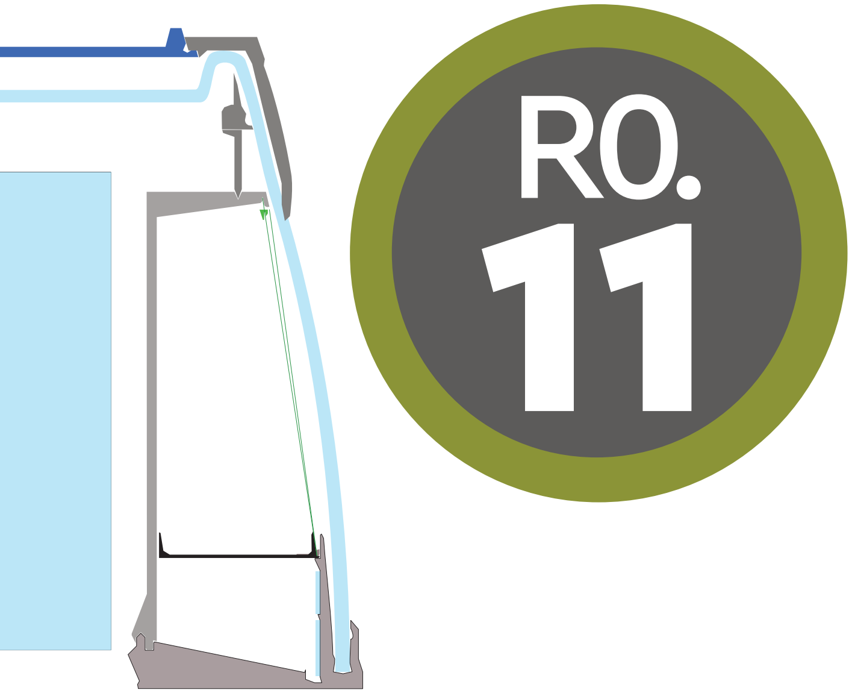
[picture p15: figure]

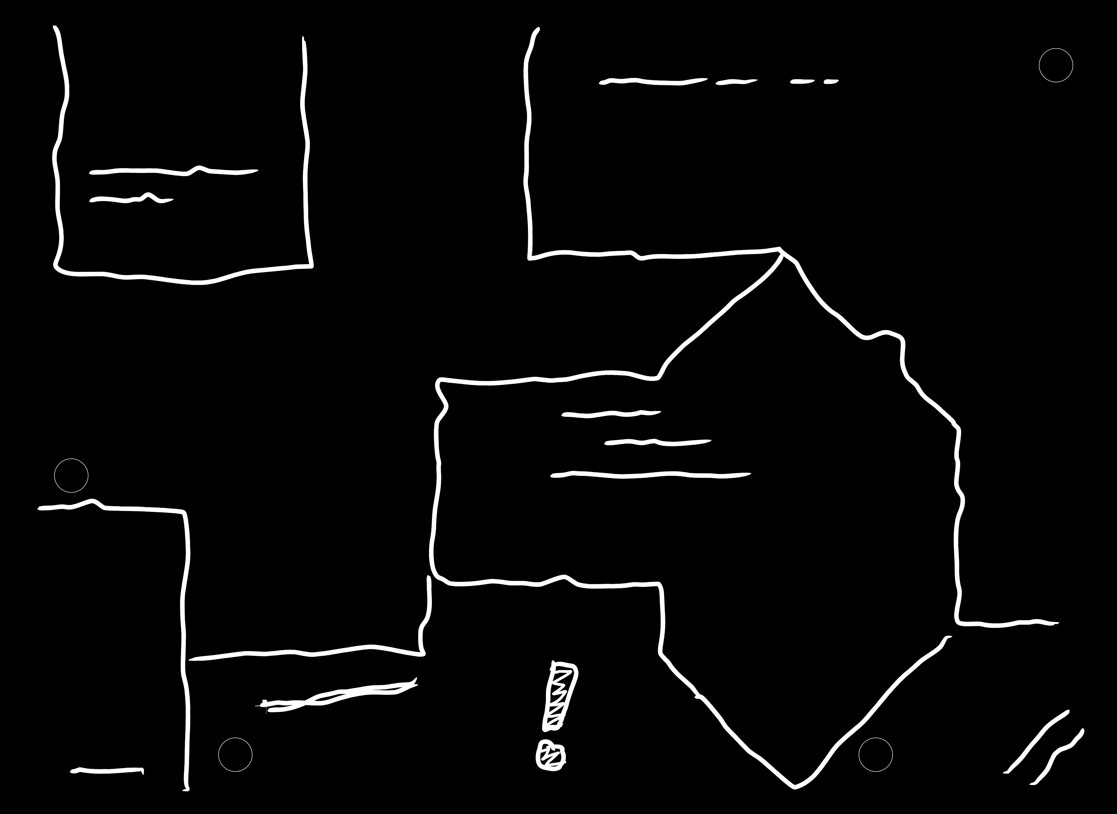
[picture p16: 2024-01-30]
hardware/mainmodule/silkscreen_back.png

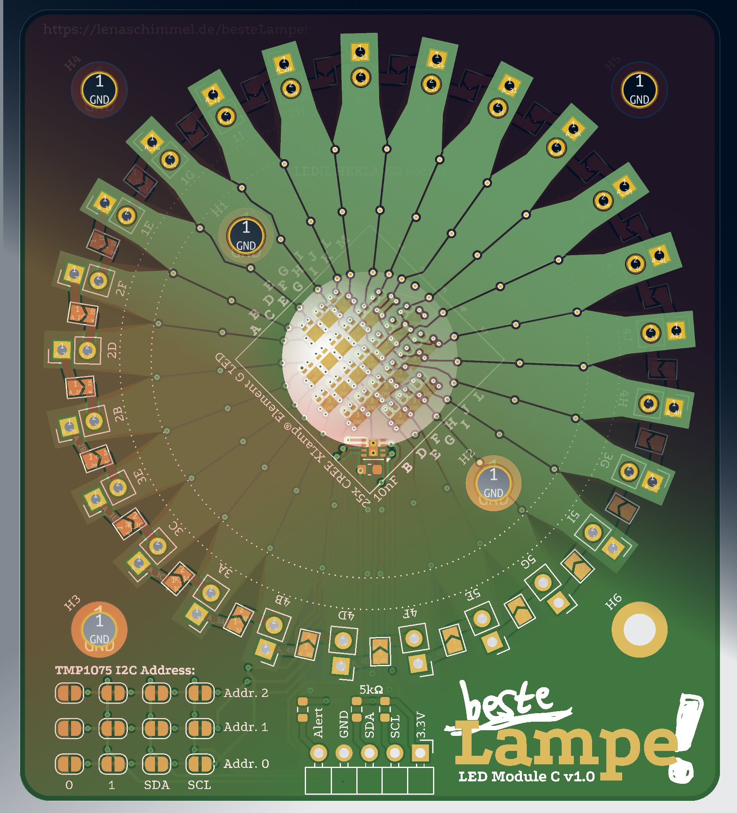
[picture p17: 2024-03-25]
assets/module_c_layers.jpg

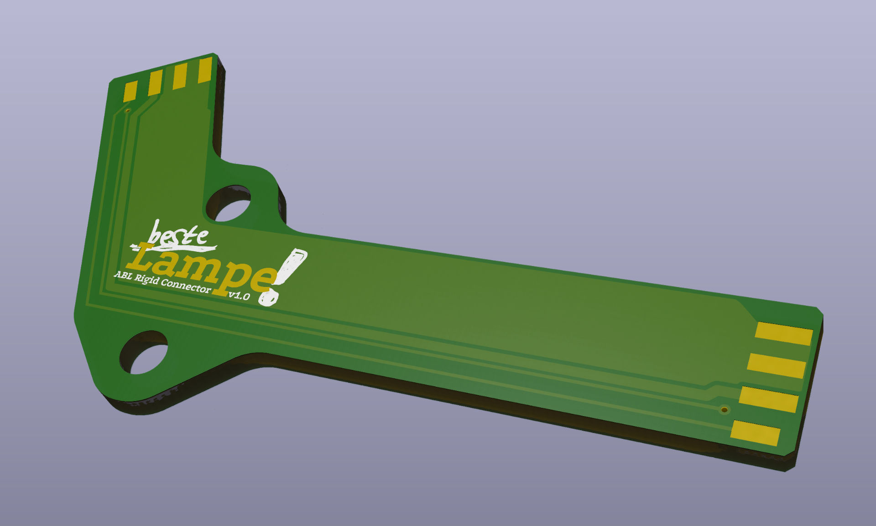
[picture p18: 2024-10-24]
assets/rendering_abl_rigid.jpg

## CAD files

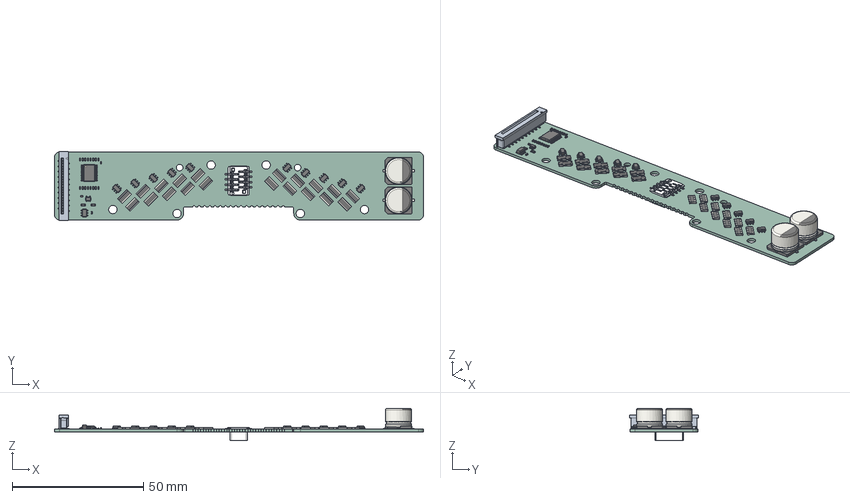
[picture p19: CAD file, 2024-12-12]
hardware/abl/LED_Module_E/LED_Module_E_cutout.step
140.8 x 26.4 x 12.4 mm
CP_Elec_10x79 x 2
R_1020_2550Metric x 20
C_0402_1005Metric x 3
R_0603_1608Metric x 2
R_0402_1005Metric x 16
TSOP_6_165x305mm_P095mm x 10
SOT_23_6
SOT_353_SC_70_5
ISFW20S-2STLF
TSSOP_20_44x65mm_P065mm
LED_Module_E_PCB

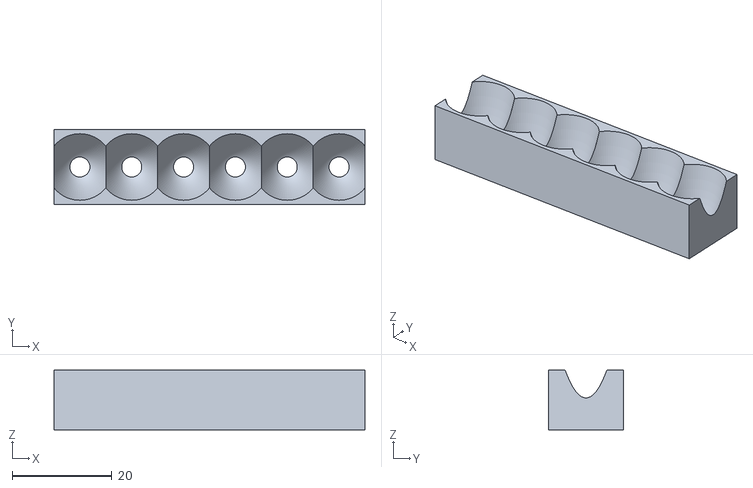
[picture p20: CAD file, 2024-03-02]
hardware/reflectors/wwcw.stl
62.4 x 15.0 x 12.0

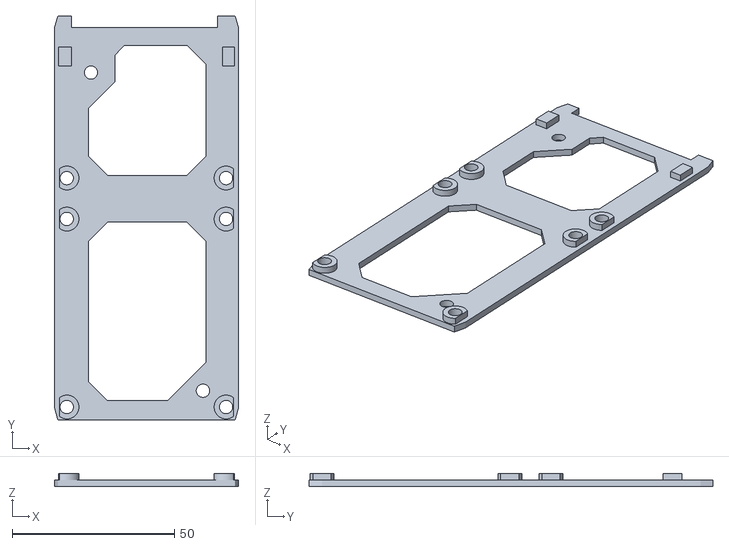
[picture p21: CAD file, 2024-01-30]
hardware/round/Halterplatte.stl
56.9 x 124.5 x 4.00

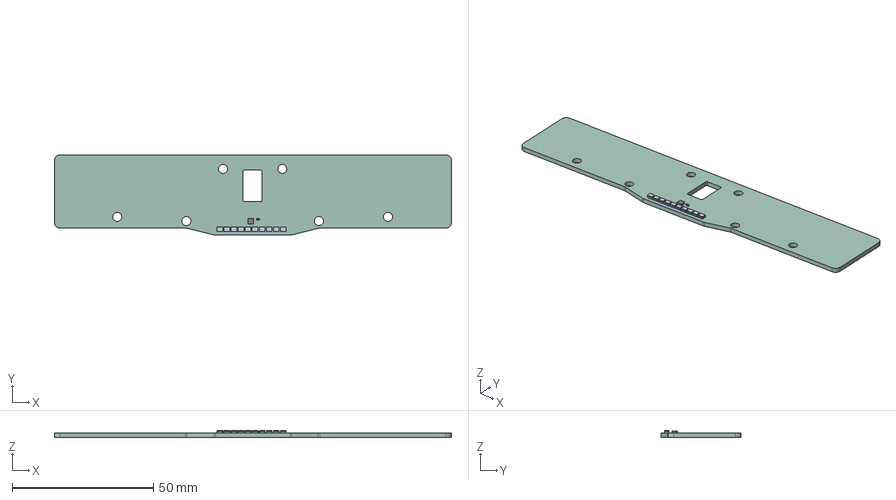
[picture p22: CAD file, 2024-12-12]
hardware/abl/LED_Module_E/LED_Module_E_copper.step
140.8 x 28.5 x 2.65 mm
C_0402_1005Metric
WSON_8_1EP_2x2mm_P05mm_EP09x16mm
_autosave-LED_Module_E_copper_PCB

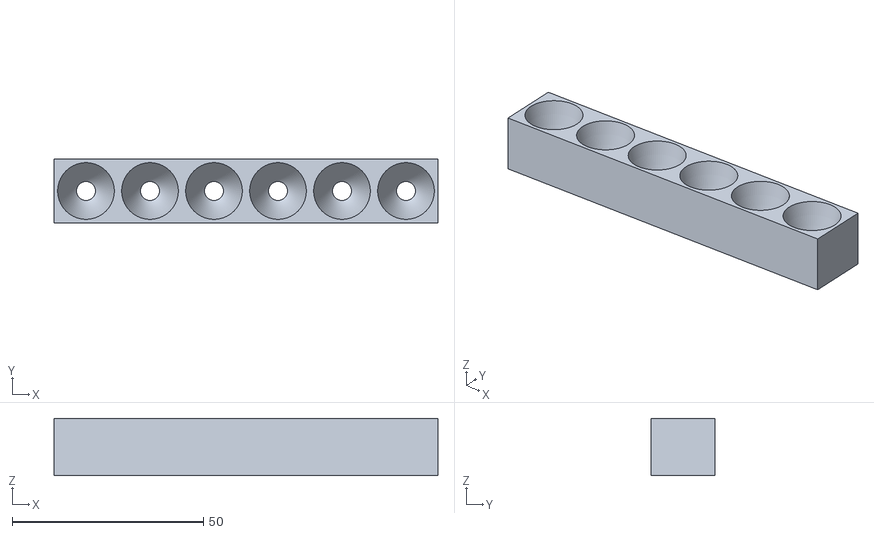
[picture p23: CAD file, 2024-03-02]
hardware/reflectors/amber.stl
100.5 x 16.8 x 15.0

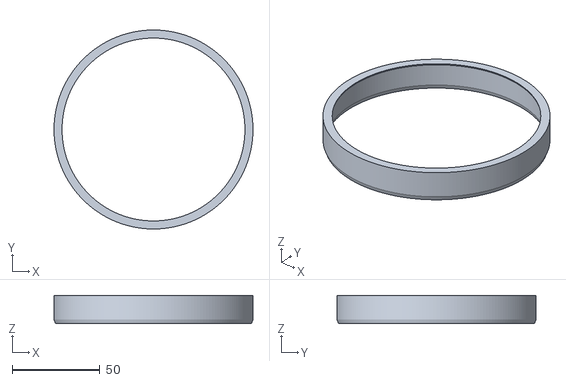
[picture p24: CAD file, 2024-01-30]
hardware/round/abstandhalter.stl
113.4 x 113.4 x 16.2

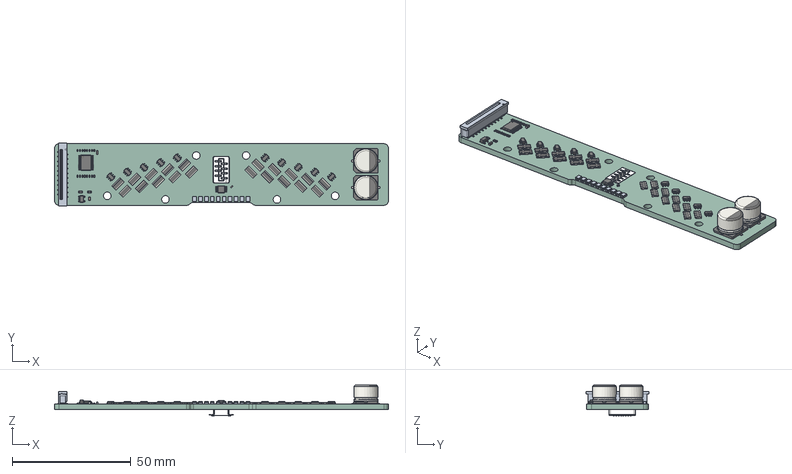
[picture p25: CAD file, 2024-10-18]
hardware/abl/LED_Module_E/LED_Module_E.step
140.8 x 26.4 x 13.0 mm
CP_Elec_10x79 x 2
R_1020_2550Metric x 20
C_0603_1608Metric x 2
R_0603_1608Metric x 2
R_0402_1005Metric x 16
TSOP_6_165x305mm_P095mm x 10
SOT_23_5
C_0402_1005Metric
ISFW20S-2STLF
TSSOP_20_44x65mm_P065mm
VSSOP_8_30x30mm_P065mm
LED_Module_E_PCB

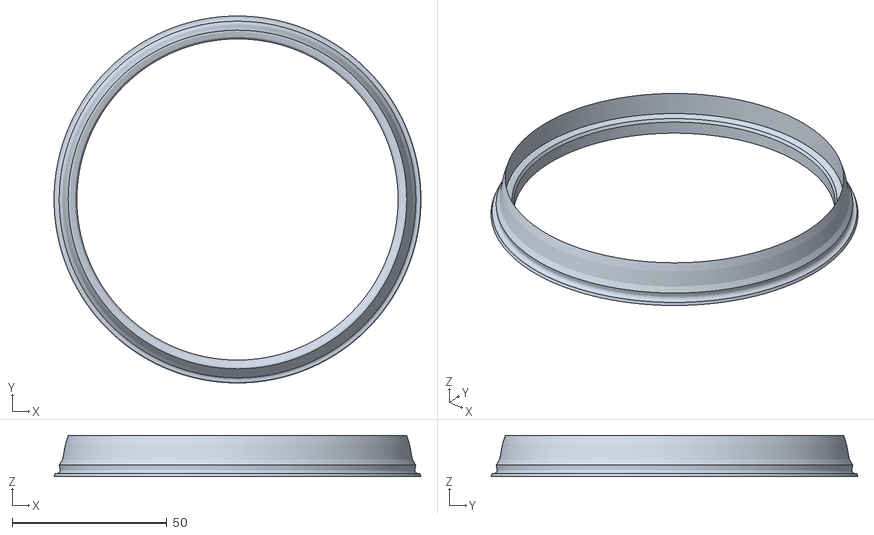
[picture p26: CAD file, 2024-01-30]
hardware/round/Hausnummernreflektor.stl
118.8 x 118.8 x 13.3

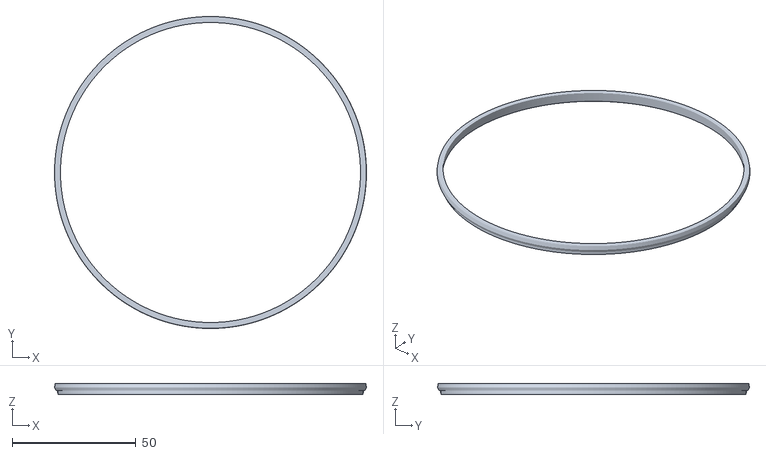
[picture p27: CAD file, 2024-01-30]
hardware/round/ObererRing.stl
126.3 x 126.3 x 4.47

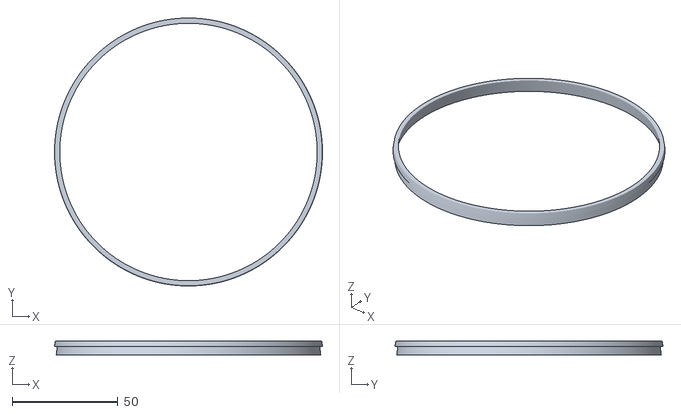
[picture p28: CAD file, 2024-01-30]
hardware/round/ObererRing2.stl
126.5 x 126.5 x 6.79

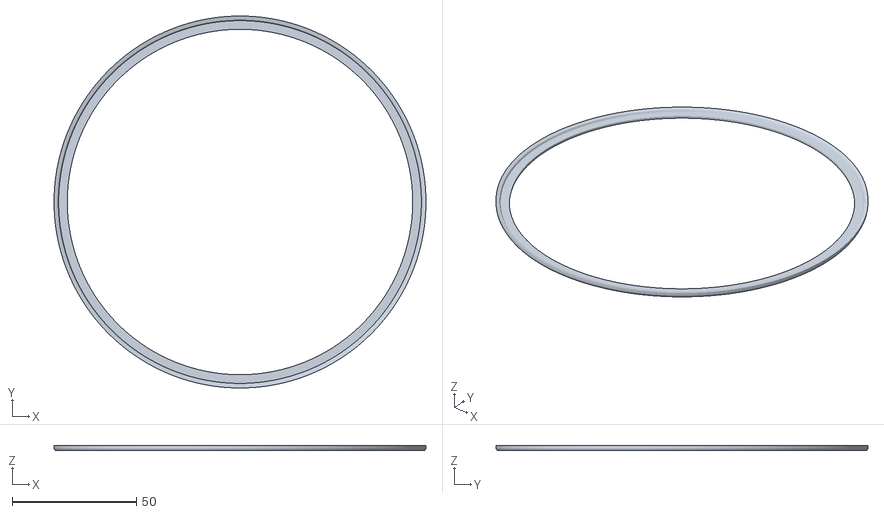
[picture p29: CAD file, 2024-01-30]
hardware/round/Spraydeckel.stl
149.8 x 149.8 x 2.05

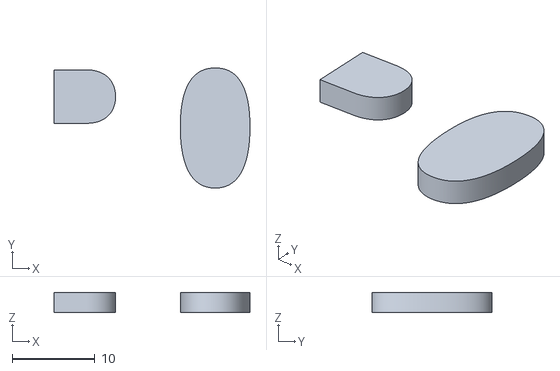
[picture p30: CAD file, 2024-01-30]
hardware/round/Nubsies.stl
23.7 x 14.5 x 2.41

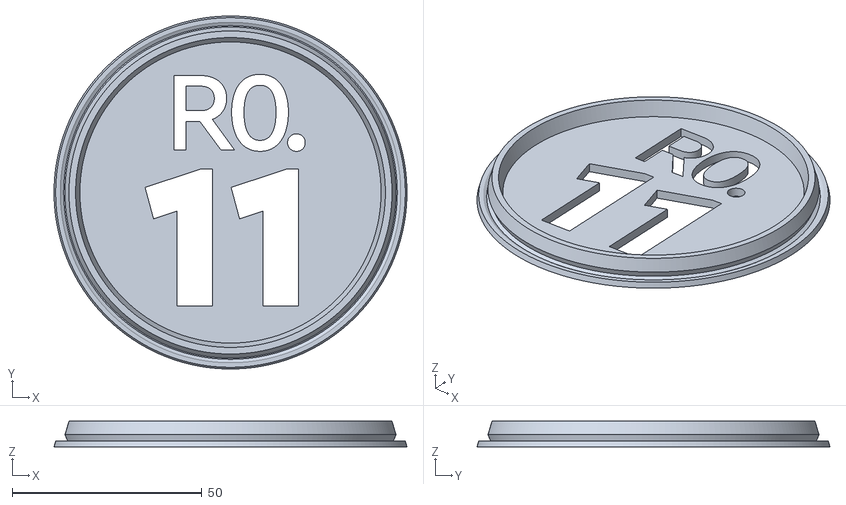
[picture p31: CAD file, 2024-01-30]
hardware/round/HausnummernscheibeNegativ.stl
92.9 x 92.9 x 6.80

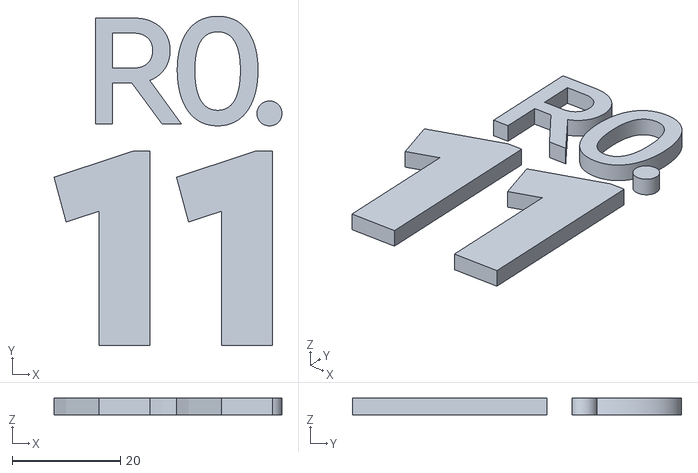
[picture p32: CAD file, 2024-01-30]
hardware/round/HausnummerPositiv.stl
42.2 x 60.9 x 3.14

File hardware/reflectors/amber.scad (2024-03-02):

// Test #1, with LED strip "warm white, cold white"
use <./paraboloid.scad>

color("blue") translate([-2.5,-2.5,-1.2]) cube([5,5,1.2]);

w = 16.75;
l = 16.75;

for (i=[0:6]) {
	translate([i*l,0,0])
	render() difference() {
		translate([-l/2,-w/2,0]) cube([l,w,15]);
		paraboloid(25, 0.65, 1, 1.3, 80);
	}
}

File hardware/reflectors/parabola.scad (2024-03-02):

/*
    parabola module from https://mastering-openscad.eu/buch/example_09/
    
    - focus_point,    focus point as 3D-vector
    - base_area,      dimension of the base are as 2D-vector
    - resolution,     number of grid points as 2D-vector

    FIXME This code generates faces with wrong orientations, which
    cannot be used in OpenSCAD for boolean operations, etc.
*/
module parabola( 
    focus_point, 
    base_area, 
    resolution = [10, 10], 
    thickness  = 0   
){
    
    function parabola_point( focus_point, base_point ) =
        let ( dist_fb = norm(focus_point - base_point) )
        [
            base_point.x,
            base_point.y,
            ( dist_fb * dist_fb ) / ( 2 * (focus_point.z - base_point.z) )
        ];
    
    function flip(vec) = [ vec[3], vec[2], vec[1], vec[0] ];

    parabola_points = [
        for ( 
            y = [0 : base_area.y / resolution.y : base_area.y + 0.1], 
            x = [0 : base_area.x / resolution.x : base_area.x + 0.1] 
        )
        parabola_point( focus_point, [x,y,0] )
    ];

    base_points = [
        for ( 
            y = [0 : base_area.y / resolution.y : base_area.y + 0.1], 
            x = [0 : base_area.x / resolution.x : base_area.x + 0.1] 
        ) 
        let ( p = parabola_point( focus_point, [x,y,0] ) )
        if (thickness > 0)
            [x, y, p.z - thickness]
        else
            [x, y, 0]
    ];

    size_x = resolution.x + 1;
                
    parabola_faces = [
        for ( 
            y = [0 : resolution.y - 1], 
            x = [0 : resolution.x - 1] 
        )
        [ 
            y    * size_x + x, 
            y    * size_x + x + 1,
           (y+1) * size_x + x + 1,
           (y+1) * size_x + x
        ]
    ];

    size_ppoints = len( parabola_points );
    
    base_faces = [
        for ( 
            y = [0 : resolution.y - 1], 
            x = [0 : resolution.x - 1] 
        )
        [ y    * size_x + x     + size_ppoints, 
          y    * size_x + x + 1 + size_ppoints,
         (y+1) * size_x + x + 1 + size_ppoints,
         (y+1) * size_x + x     + size_ppoints]
    ];


    side_faces_1 = [
        for ( x = [0 : resolution.x - 1] )
        [ x, 
          x + 1, 
          x + 1 + size_ppoints, 
          x     + size_ppoints ]
    ];


    last_row = resolution.y * size_x;
        
    side_faces_2 = [
        for ( x = [0 : resolution.x - 1] )
        [ 
            last_row + x, 
            last_row + x + 1, 
            last_row + x + 1 + size_ppoints, 
            last_row + x     + size_ppoints
        ]
    ];

    side_faces_3 = [
        for ( y = [0 : resolution.y - 1] )
        [ 
            y      * size_x, 
           (y + 1) * size_x, 
           (y + 1) * size_x + size_ppoints, 
            y      * size_x + size_ppoints 
        ]
    ];

    last_col = resolution.x;

    side_faces_4 = [
        for ( y = [0 : resolution.y - 1] )
        [ 
            last_col +  y      * size_x, 
            last_col + (y + 1) * size_x, 
            last_col + (y + 1) * size_x + size_ppoints, 
            last_col +  y      * size_x + size_ppoints
        ]
    ];

    polyhedron(
        points = concat( parabola_points, base_points ), 
        faces  = concat( parabola_faces, 
                         base_faces, 
                         side_faces_1,
                         side_faces_2,
                         side_faces_3,
                         side_faces_4)
    );
    
}

render()
parabola( 
    focus_point = [75,75,100],
    base_area   = [150,150],
    thickness   = 0
);

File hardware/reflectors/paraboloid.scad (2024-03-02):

//////////////////////////////////////////////////////////////////////////////////////////////
// Paraboloid module for OpenScad
//
// Copyright (C) 2013  Lochner, Juergen
// http://www.thingiverse.com/Ablapo/designs
//
// This program is free software. It is 
// licensed under the Attribution - Creative Commons license.
// http://creativecommons.org/licenses/by/3.0/
//////////////////////////////////////////////////////////////////////////////////////////////
//Edited by Takuya Yamaguchi for making customaizable.
//////////////////////////////////////////////////////////////////////////////////////////////

//height of paraboloid
y=50 ; //[0:100]

//focus distance
f=10;	//[0:100]

//center paraboloid position
fc=1;	// [1,0]

//radius of the focus area :
rfa=0 ;//[0:100]

// detail = $fn of cone
detail=120; //[44:240]

module paraboloid (y, f, rfa, fc, detail){
	// y = height of paraboloid
	// f = focus distance 
	// fc : 1 = center paraboloid in focus point(x=0, y=f); 0 = center paraboloid on top (x=0, y=0)
	// rfa = radius of the focus area : 0 = point focus
	// detail = $fn of cone

	hi = (y+2*f)/sqrt(2);								// height and radius of the cone -> alpha = 45° -> sin(45°)=1/sqrt(2)
	x =2*f*sqrt(y/f);									// x  = half size of parabola
	
   translate([0,0,-f*fc])								// center on focus 
	rotate_extrude(convexity = 10,$fn=detail )		// extrude paraboild
	translate([rfa,0,0])								// translate for fokus area	 
	difference(){
		union(){											// adding square for focal area
			projection(cut = true)																			// reduce from 3D cone to 2D parabola
				translate([0,0,f*2]) rotate([45,0,0])													// rotate cone 45° and translate for cutting
				translate([0,0,-hi/2])cylinder(h= hi, r1=hi, r2=0, center=true, $fn=detail);   	// center cone on tip
			translate([-(rfa+x ),0]) square ([rfa+x , y ]);											// focal area square
		}
		translate([-(2*rfa+x ), -1/2]) square ([rfa+x ,y +1] ); 					// cut of half at rotation center 
	}
}

paraboloid (y, f, rfa, fc, detail);

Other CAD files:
hardware/round/ringuntenkleb.stl
hardware/round/Hauptreflektor.stl
hardware/round/Inlay.stl
hardware/round/HausnummernscheibeMassiv.stl
hardware/reflectors/wwcw.scad
hardware/round/floor.scad
hardware/round/number.scad
hardware/round/rings.scad
hardware/round/rings.stl

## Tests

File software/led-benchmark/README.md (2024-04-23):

<!--
SPDX-FileCopyrightText: 2024 Lena Schimmel <mail@lenaschimmel.de>
SPDX-License-Identifier: CC-BY-SA-4.0

[besteLampe!](https://lenaschimmel.de/besteLampe!) © 2024 by [Lena Schimmel](mailto:mail@lenaschimmel.de) is licensed under [CC BY-SA 4.0](http://creativecommons.org/licenses/by-sa/4.0/?ref=chooser-v1)
-->

## led-benchmark
This project is used to drive LEDs using different driver circuits and PWM generators, and benchmark several properties.

Measured values:
 - Brightness (VEML6040)
 - Color temperature (VEML6040)
   - *I do not yet have the correct code to compute the color temperature, so I will save the four sensor values (RGBW) separately for later processing*
 - Power consumption (INA219)
 - Temperature (heat) of the LEDs and/or driver (TMP1075 and/or some DS18B20 variant)

The LEDs may differ by:
 - type
 - count (usually in series)
 - cooling

The driver electronic may differ by:
 - model of the CCD IC
 - inductor
 - CCD switching frequency
 - (desired) current at 100% duty cycle
 - input voltage

The software changes these parameters:
 - PWM frequency
 - duty cycle

It's obvious that I can't test every possible combination of those parameters, especially not those that require me to build different driver boards.

### Needed hardware
- LED controlled by PWM signal from GPIO 11
- I2C Bus with SDA on GPIO 23 and SCL on GPIO 22
- INA219 on I2C with address 64 (sadly hardcoded in the fork that I use)
  - The measured current is completely wrong. Not sure if wrong calibration, other software error or I connected my wires incorrectly
- TMP1075 on I2C with address 77

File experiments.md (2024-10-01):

<!--
SPDX-FileCopyrightText: 2024 Lena Schimmel <mail@lenaschimmel.de>
SPDX-License-Identifier: CC-BY-SA-4.0

[besteLampe!](https://lenaschimmel.de/besteLampe!) © 2024 by [Lena Schimmel](mailto:mail@lenaschimmel.de) is licensed under [CC BY-SA 4.0](http://creativecommons.org/licenses/by-sa/4.0/?ref=chooser-v1)
-->

<!-- *Apart from this README, most documentation and notes are in German. If this project becomes more than a proof-of-concept, all important parts the documentation will be translated to English. The name will remain German, as it should be understandable to English speakers as well.* -->

# Outdated information about early experiments
_Initially this repository contained a lot of different approaches to build the lamp, many of which are no longer revelevant. The following texts were moved from the main README of the repository._

## Parts and Modules
The besteLampe! project has multiple parts. In the future, they might be moved into separate repositories. They are:

 - Hardware
   - 🟢 **[Main module](hardware/mainmodule/)** • Control board with power supply, micro controller, 6-channel PWM (pulse width modulation) dimmer and many ports. *First version shipped and tested*
   - 🔴 **Extension module** • Additional simultaneous wireless protocols, 16 additional PWM channels.
   - 🟢 **LED modules** • Stuff that actually emits light. *only handmade prototypes*
   - 🟡 **Enclosure** • To hold the electronics together, protect it from the environment, and guide the light.
 - Software
   - 🟢  **[Firmware](software/bestelampe) for main- and extension module**
   - 🟡 **Control software (Web, Desktop, Mobile, CLI, M5Paper...)**
   - 🔴 **Common code library** • The firmware and all control software variants are written in Rust and should all use a common, portable code base.

In the initial concept, hardware modules are intended like to be used like this:

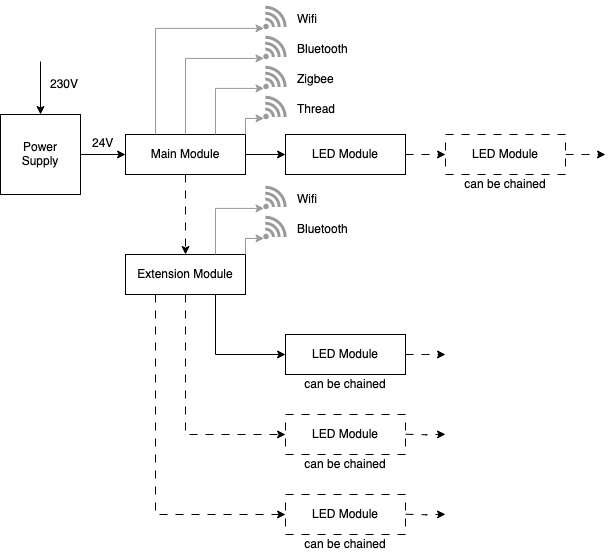
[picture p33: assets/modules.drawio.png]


- The main module with its ESP32-C6 can control one chain of LED modules (within a chain, all modules show the same color/brightness). It offers four wireless protocols, but only one or two of them can be used at the same time.
- The extension module can control up to three chains of LED modules (each chain has individual color/brightness). Its ESP32 only has two wireless protocols, but they can be used at the same time, so that a total of three protocols can be combined.

I'm currently exploring a different approach, starting with LED Module C, which might need changes to the whole modularization concept. Stay tuned...

## State of the project
### Documentation
This readme is not up-to-date. Both software and hardware are already more advanced than what the next paragraphs describe. Please look at the source code and/or the LED Modules' READMEs in the `hardware` directory to get a better impression of the current state.

### Software
The firmware is currently in a transformation from messy, quick-and-dirty proof-of-concept to a more structured and reliable architecture. It supports all hardware components of the Main Module v1 and LED Module A.

Possible next steps:
 - Move code between bestelampe (hardware-dependent) and abstraktelampe (hardware-independent)
 - Make PWM fading, 20 bit resoluition and temporal dithering are available in Rust (only partly supported by esp-idf-hal)

### Hardware
For the hardware, multiple prototypes with various degrees of sophistication exist:

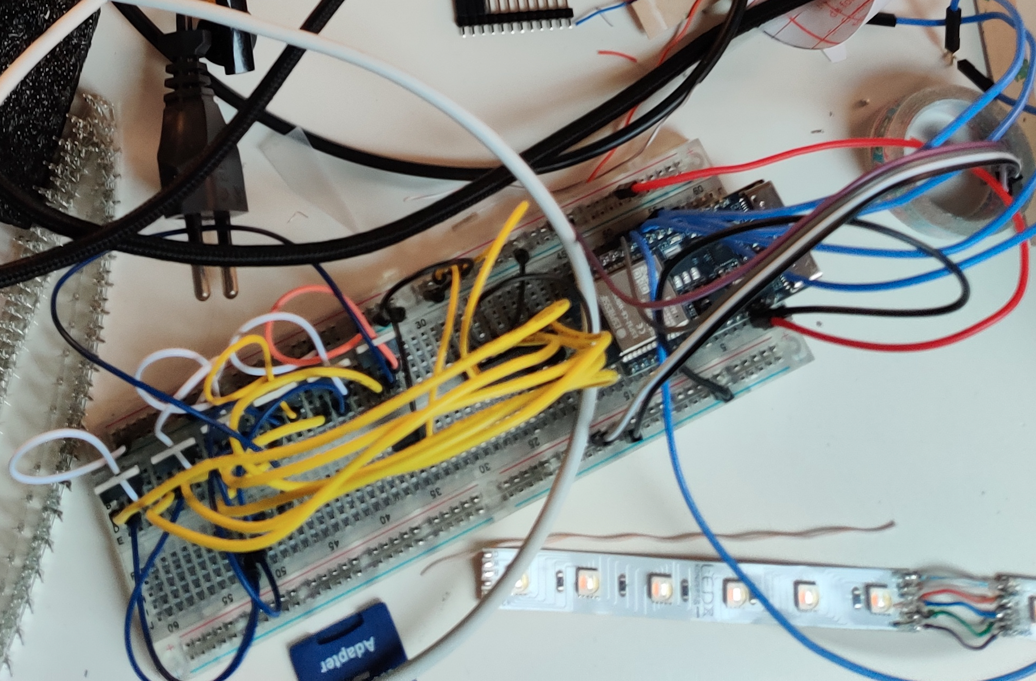
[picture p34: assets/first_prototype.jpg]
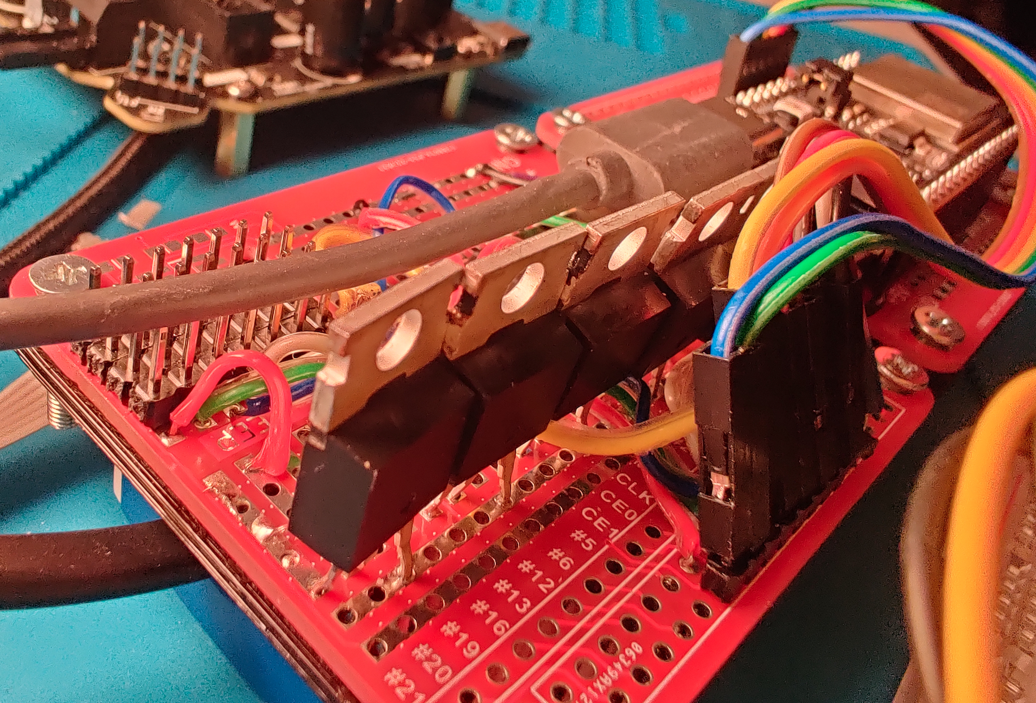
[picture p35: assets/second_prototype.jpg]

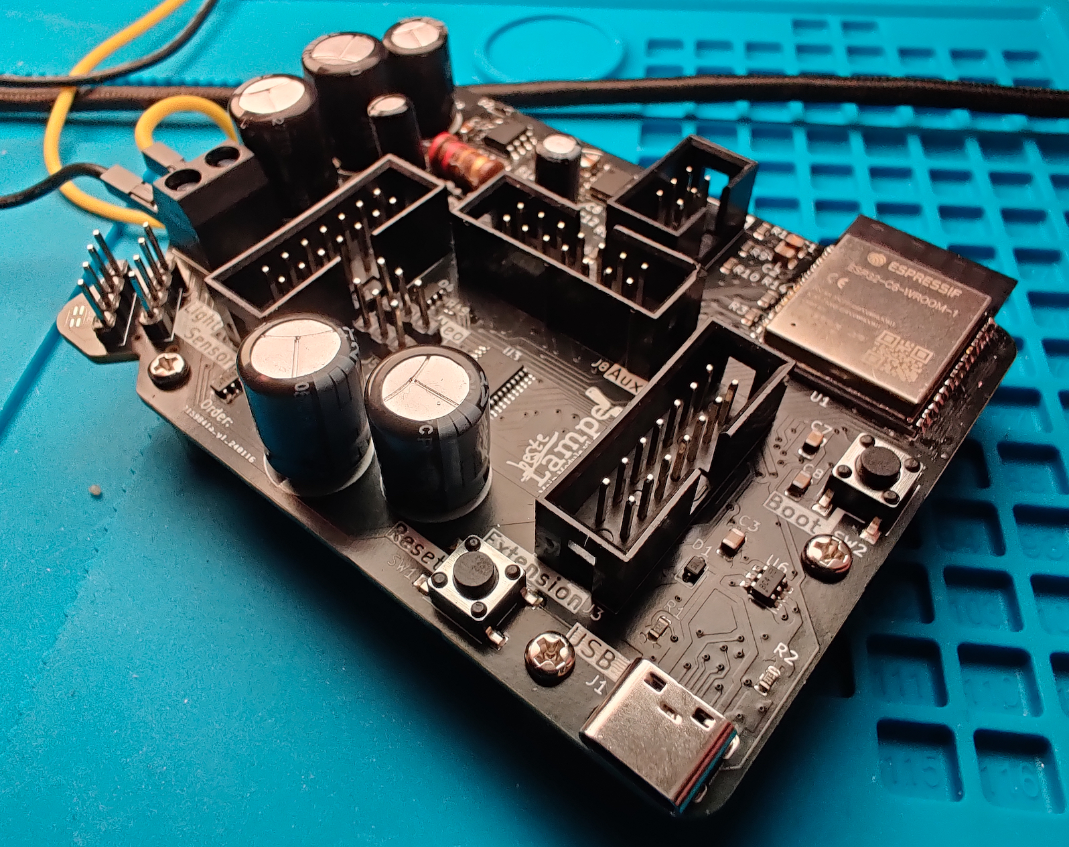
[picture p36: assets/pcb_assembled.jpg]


I already ordered PCBs from JLCPCB for the Main Module v1, and even though they have [a lot of minor bugs](/hardware/mainmodule/README.md#Known-problems-for-v1), they look great and - even more important - are fully functional apart from the missing light sensor. **I do not recommend to order Main Module v1.** There are a lot of really easy-to-fix nuisances, so please wait for version 1.1 (see branch [`main-module-v1.1`](https://github.com/lenaschimmel/bestelampe/tree/main-module-v1.1)) or version 2. **If you really want a v1 board in your hands quickly, just contact me. I have a few spare ones (partly assembled).**

Some LED boards are also designed and have been manufactured.

I'm working on multiple enclosure designs, one based on a transparent flower pot, and one based on an existing lamp where I replace all the electronics with my own. Both contain many 3d-printed parts,  and a lot of manual labour to make them look *less 3d-printed*.

The next steps for the hardware could be:
 - Release Main Module v1.1
 - Put a second ESP32 into the prototype to test ESP-AT or similar communication between both ESPs
 - Create constant-current PWM driver for LED Board C.

 ## Price
 I've tried to estimate the prices for a complete lamp, but excluding the enclosure (because I have no idea how to estimate that). The calculation is based on ordering 100 PCBs per type, and some optimizations in Main Module v1.1, some of which are not yet done. 
 
 The two lamp configurations are:
 - **Simple:** 6 color channels (R,G,B,Warm White, Cold White, Amber). Needs the Main Module and 1 LED Module
 - **Extended:** 4*6 color channels (same colors as above, but control 4 groups independently). Needs the Main Module, Extension Module and 4 LED Modules. To drive all four groups at full brightness simultaneously, you'd need a bigger power supply.

 | **Part**                      | **Price (Euro)** | **Comment**                                    | **Count in simple lamp** | **Count in extended lamp** |
|-------------------------------|------------------|------------------------------------------------|--------------------------|----------------------------|
| Main Module v1.1              | 10.80            | incl. SMD and through-hole components          | 1                        | 1                          |
| Power supply                  | 14.00            | 15W, input 220-240V AC, output 24V DC          | 1                        | 1                          |
| Presence sensor               | 3.00             |                                                | 1                        | 1                          |
| Extension module              | 13.00            | very rough estimate                            | 0                        | 1                          |
| LED module                    | 5.70             | Assuming RGBCCT and Amber LEDs, 20 pieces each | 1                        | 4                          |
| **Sum: Simple besteLampe!**   | **33.50**        | Enclosure not included                         |                          |                            |
| **Sum: Extended besteLampe!** | **63.60**        | Enclosure not included                         |                          |                            |

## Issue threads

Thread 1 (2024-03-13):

LED pin numbering is inconsistend between symbols, footprints and standad convention

lenaschimmel, 2024-03-13:
This is a general warning that something is off here. I'm not yet sure about all the details.

At first I noticed that some LEDs in my LED Board A2 v1.0 (may not be committed and pushed at the time of this writing) did not light up, because I soldered them the wrong way. When I checked the PCB and Schematic in KiCad, I found that everything is chaos and it's a mystery how in the end only one chain of LEDs ended up in the wrong direction in the physical board.

- Symbols
  - `LED:LED_Thermal_Pad` (from Library)
    - 1=K, 2=A, 3=Thermal
  - `LED_CREE_JSE28L3E5_Group_2` (self-drawn based on some existing symbol)
    - 1=A, 2=K
  - `LED_CREE_JSE28L3E5_Group_2` (self-drawn based on some existing symbol)
    - 1=K, 2=A
- Footprints
  - `LED_SMD:Luminous Devices A130 Package` (self-drawn)
    - 1=K, 2=A, 3=Thermal
    - but silkscreen with a dot and a small "A" at the "K"-side
  - `LED_SMD:LED_2835_CREE_JSE28L3E5_Big_Anode` (self-drawn)
    - 1=A (big), 2=K (small)
    - silkscreen open at the "A"-side
  - `LED_SMD:LED_2835_CREE_JSE28L3E5_1` (self-drawn)
    - 1=A (big), 2=K (small)
    - silkscreen open at the "K"-side

According to [this comment](https://github.com/KiCad/kicad-library/issues/291#issuecomment-139909773): **"K=1, A=2 is common standard that we should follow."**

So the three-pin LED is the only one that has the correct order in the Symbol and in the Footprint, yet the only one that I soldered incorrectly due to the error in the silkscreen.

To make things more even complicated: I knew early on that CREE LEDs would have conflicting pin assignments with the J-series, depending on color. For some, the bigger pad is the Cathode (K), for some, the bigger one is the Anode (A). When I first ordered a PCM with assembly for the LEDs (Board A version 1.0), I made sure to make it clear to the manufacturer how the LEDs should fit. But in the exported BOM, the rotation angles seemed off.

For unrelated reasons, I had to redo large parts of the PCB layout to make it possible to manufacture. or the re-upload, I cleaned up the symbols and/or footprints of the LEDs to make it less confusing (and of course told the manufacturer about the change). Because the first upload was never manufactured, I kept the version number at 1.0.

I think my "clean up" might have made it worse, also it means that there could be older versions of these symbols and/or footprints somewhere in this repo that are different from what I described above.

As a solution, I think I need to:
 - learn how to organize symbols and footprints across multiple KiCad projects.
 - redo all the footprints and symbols to meet the common standard K=1, A=2
 - do not re-use the old names for the new ones
 - clean up all schematics and PCBs to use the new ones

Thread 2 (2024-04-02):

Connector on LED Module A v1.0 placed incorrectly

lenaschimmel, 2024-04-02:
The connector on LED Module A v1.0 placed is placed too close to both edges of the bounding box of the PCB. Actually, not only the connector has to be moved - the PCB outline must be adjusted a bit to make it fit.

My PCB order arrived today (after six weeks). I could confirm that the boards fit into the Steinel enclosure that I use(d) for testing, but only if no cable is connected to the connector. With the cable connected, it does not fit into the enclosure.

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

I think I will release a version 1.1 where this will be fixed, but this has very low priority for me.

I will also create an adapter that can be used to work with the PCBs as they are, and I will release the files for the adapter as well.

Anyway: I do not recommend ordering these boards, no matter if with or without those fixes. LED Module **A2** v1.0 does not have these problems, and will be cheaper / quicker to produce.

lenaschimmel, 2024-04-02:
Note to self: this adapter should also fix the slight pin incompatibilities between the boards A and A2, by not connecting the critical pins straight through, but optionally leading them to extra pads.

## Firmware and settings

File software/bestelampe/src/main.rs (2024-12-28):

// SPDX-FileCopyrightText: 2024 Lena Schimmel <mail@lenaschimmel.de>
// SPDX-License-Identifier: CERN-OHL-S-2.0+
// This file is part of besteLampe!.
// 
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
// besteLampe! is distributed in the hope that it will be useful, but WITHOUT ANY WARRANTY; 
// without even the implied warranty of MERCHANTABILITY or FITNESS FOR A PARTICULAR PURPOSE. 
// See the GNU General Public License for more details.
// 
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
use std::thread;
use std::sync::{Arc, RwLock};

use esp_idf_hal::gpio::DriveStrength;
use esp_idf_hal::{
    prelude::*,
    gpio::{AnyIOPin, PinDriver},
};

use esp_idf_svc::{
    log::EspLogger,
    sntp,
};

use ::function_name::named;
use chrono_tz::Tz;
use chrono::Utc;

use log::*;
mod pwm;

mod task;
use crate::task::buttons::test_buttons;
use crate::task::leds::test_leds;
use crate::task::ota::test_ota;
use crate::task::presence::test_presence_sensor;
use crate::task::server::run_server;
use crate::task::thermal::test_thermal_sensor;
use crate::task::wifi::start_wifi;
use crate::task::light_sensor::test_light_sensor;
use crate::task::i2c::test_i2c;
use crate::task::uart::test_uart;

extern crate ina219;

mod config;
use crate::config::CONFIG;

mod prelude {
    pub use log::*;
    pub use ::function_name::named;
    pub use crate::config::CONFIG;
    pub use anyhow::{ Result, anyhow };
}

#[named]
fn main() -> ! {
    esp_idf_svc::sys::link_patches();
    EspLogger::initialize_default();
    debug!(target: function_name!(), "Logger initialized.");
    
    // Thread safe globals for communication across tasks
    let thermal: Arc<RwLock<f32>> = Arc::new(RwLock::new(0.0));
    let voltage: Arc<RwLock<f32>> = Arc::new(RwLock::new(0.0));
    let current: Arc<RwLock<f32>> = Arc::new(RwLock::new(0.0));
    let light_temperature_target: Arc<RwLock<f32>> = Arc::new(RwLock::new(3000.0));
    let light_brightness_target: Arc<RwLock<f32>> = Arc::new(RwLock::new(0.001));
    let light_dim_speed: Arc<RwLock<f32>> = Arc::new(RwLock::new(0.01));
    let update_requested: Arc<RwLock<bool>> = Arc::new(RwLock::new(false));
    let time_offset: Arc<RwLock<i64>> = Arc::new(RwLock::new(0));
    
    let peripherals: Peripherals = Peripherals::take().expect("Need Peripherals.");


    // I2C
    let pin_i2c_pwr : AnyIOPin = peripherals.pins.gpio20.into();
    let mut out_i2c_pwr = PinDriver::output(pin_i2c_pwr).unwrap();
    out_i2c_pwr.set_high();
    

    let thermal_for_i2c = thermal.clone();
    let voltage_for_i2c = voltage.clone();
    let current_for_i2c = current.clone();
    let time_offset_for_i2c = time_offset.clone();
    let i2c = peripherals.i2c0;
    let _i2c_thread = thread::spawn(|| {
        test_i2c(
            i2c, 
            peripherals.pins.gpio18.into(), 
            peripherals.pins.gpio19.into(), 
            thermal_for_i2c, 
            voltage_for_i2c, 
            current_for_i2c,
            time_offset_for_i2c,
        ).unwrap_or_default();
        error!(target: function_name!(), "I2C thread has ended :(");
    });

    // // Serial / UART, configured for GPS time
    // let time_offset_for_uart = time_offset.clone();
    // let _uart_thread = thread::spawn(|| {
    //     test_uart(
    //         peripherals.pins.gpio8.into(),
    //         peripherals.pins.gpio0.into(),
    //         peripherals.uart1, time_offset_for_uart
    //     ).unwrap_or_default();
    //     error!(target: function_name!(), "UART thread has ended :(");
    // });

    // // Light sensor
    // let i2c = peripherals.i2c0;
    // let _light_sensor_thread = thread::spawn(|| {
    //     test_light_sensor(i2c, peripherals.pins.gpio6.into(), peripherals.pins.gpio7.into()).unwrap_or_default();
    //     error!(target: function_name!(), "Light sensor has ended :(");
    // });

    // Buttons
    // let light_brightness_target_clone_for_buttons = light_brightness_target.clone();
    // let light_temperature_target_clone_for_buttons = light_temperature_target.clone();
    // let light_dim_speed_for_buttons = light_dim_speed.clone();
    // let _button_thread = thread::spawn(|| {
    //     let pin_a : AnyIOPin = peripherals.pins.gpio22.into();
    //     let pin_b : AnyIOPin = peripherals.pins.gpio23.into();
    //     let pin_c : AnyIOPin = peripherals.pins.gpio0.into();
    //     test_buttons(pin_a, pin_b, pin_c, light_brightness_target_clone_for_buttons, light_temperature_target_clone_for_buttons, light_dim_speed_for_buttons).unwrap_or_default();
    //     error!(target: function_name!(), "Button thread has ended :(");
    // });

//    // Temperature sensor
//     let _thermal_thread = thread::spawn(|| {
//         let pin_driver = PinDriver::input_output(peripherals.pins.gpio15).expect("Should be able to take Gpio15 for temperature measurement.");
//         test_thermal_sensor(pin_driver, thermal);
//     });

    // To use the RMT periferal as a fake UART controller, we could use peripherals.rmt.channel2, // Only channel 2 and 3 can RX

    // // Presence sensor
    let light_brightness_target_clone_for_presence = light_brightness_target.clone();
    let _presence_thread = thread::spawn(|| {
        test_presence_sensor(
            peripherals.pins.gpio17.into(),
            peripherals.pins.gpio16.into(), 
            peripherals.uart1,
            light_brightness_target_clone_for_presence).unwrap();
        warn!("Presence sensor thread has ended :(");
    });
    
    // LED control
    let light_temperature_target_clone = light_temperature_target.clone();
    let light_brightness_target_clone = light_brightness_target.clone();
    let light_dim_speed_clone = light_dim_speed.clone();
    let _led_thread = thread::spawn(|| {
        let ledc = peripherals.ledc;
        let pin_r  : AnyIOPin = peripherals.pins.gpio22.into();  // LED 8
        let pin_g  : AnyIOPin = peripherals.pins.gpio2.into();   // LED 6
        let pin_b  : AnyIOPin = peripherals.pins.gpio6.into();   // LED 3
        let pin_cw : AnyIOPin = peripherals.pins.gpio5.into();   // LED 4 
        let pin_nw : AnyIOPin = peripherals.pins.gpio21.into();   // LED 7
        let pin_ww : AnyIOPin = peripherals.pins.gpio1.into();   // LED 1
        let pin_a  : AnyIOPin = peripherals.pins.gpio4.into();   // LED 2
        let pin_pa : AnyIOPin = peripherals.pins.gpio3.into();   // LED 5
  
        test_leds(
            ledc,
            pin_r,
            pin_g,
            pin_b,
            pin_cw,
            pin_nw,
            pin_ww,
            pin_a,
            pin_pa,
            light_temperature_target_clone,
            light_brightness_target_clone,
            light_dim_speed_clone
        ).expect("LEDs should just work.");
    });

    // // OTA
    // let update_requested_clone = update_requested.clone();
    // let _ota_thread = thread::spawn(|| {
    //     if let Err(err) = test_ota(update_requested_clone) {
    //         println!("test_ota returned {:#?}", err);
    //     }
    // });

    // Wifi & web interface server
    let light_brightness_target_for_server = light_brightness_target.clone();
    let _wifi_thread = thread::spawn(|| {
        start_wifi(peripherals.modem, CONFIG.wifi_ap_active).unwrap();
        let _sntp = sntp::EspSntp::new_default().unwrap();
        info!(target: function_name!(), "SNTP initialized");
        run_server(light_temperature_target, light_brightness_target_for_server, light_dim_speed, update_requested, thermal, voltage, current).unwrap();
    });

    let tz: Tz = CONFIG.time_zone.parse().unwrap();


    let led_en_pin : AnyIOPin = peripherals.pins.gpio14.into();
    let mut led_en = PinDriver::output(led_en_pin).unwrap();
    led_en.set_high(); // high = disabled

    // Keep the main thread alive
    info!(target: function_name!(), "Entering infinite loop in main thread...");
    let mut count: u8 = 0;
    loop {
        let now = Utc::now();
        let local_now = now.with_timezone(&tz);
        //trace!("Current time: {:?}", local_now);
        std::thread::sleep(core::time::Duration::from_millis(1000));
        //info!(target: function_name!(), "LED enable / alert : {:?}", led_en.get_level());
        if(count < 10) {
            count += 1;
            if (count == 4) {
                led_en.set_low(); // low = enabled    
                *light_brightness_target.write().unwrap() = 0.0;
            }
        }
    }
}

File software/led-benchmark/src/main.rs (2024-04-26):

// SPDX-FileCopyrightText: 2024 Lena Schimmel <mail@lenaschimmel.de>
// SPDX-License-Identifier: CERN-OHL-S-2.0+
// This file is part of besteLampe!.
// 
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
// besteLampe! is distributed in the hope that it will be useful, but WITHOUT ANY WARRANTY; 
// without even the implied warranty of MERCHANTABILITY or FITNESS FOR A PARTICULAR PURPOSE. 
// See the GNU General Public License for more details.
// 
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
// -----
//
// This project is used to drive LEDs using different driver circuits and PWM generators,
// and benchmark several properties. See the README.md for mor information.

use std::cell::RefCell;

use esp_idf_sys::{esp, esp_vfs_dev_uart_use_driver, uart_driver_install};
use esp_idf_sys::ESP_FAIL;

use esp_idf_hal::{
    prelude::*,
    gpio::*,
    peripherals::Peripherals,
    i2c::{I2cConfig, I2cDriver},
    ledc::{LedcDriver, LedcTimerDriver, config::TimerConfig},
};

use embedded_hal::pwm::SetDutyCycle;

use embedded_hal_bus::{
    i2c as i2c_bus,
};

use std::{
    time::Duration,
    ptr::null_mut,
    thread,
};

use veml6040::wrapper::AutoVeml6040;

use lm75::{Lm75, Address};

extern crate ina219_rs as ina219;

use ina219::ina219::{INA219, Calibration};

fn main() -> anyhow::Result<()>  {
    // It is necessary to call this function once. Otherwise some patches to the runtime
    // implemented by esp-idf-sys might not link properly. See https://github.com/esp-rs/esp-idf-template/issues/71
    esp_idf_svc::sys::link_patches();

    // Needed to accept input via serial connection:
    unsafe {   
        esp!(uart_driver_install(0, 512, 512, 10, null_mut(), 0)).unwrap();
        esp_vfs_dev_uart_use_driver(0);
    }

    // Bind the log crate to the ESP Logging facilities
    esp_idf_svc::log::EspLogger::initialize_default();

    run_benchmark()?;

    Ok(())
}


fn run_benchmark() -> anyhow::Result<()> {
    let peripherals = Peripherals::take()?;

    println!("Initialize the LED and LEDC for direct PWM output...");
    let led_pin = peripherals.pins.gpio11;    
    let ledc = peripherals.ledc;
    let mut timer_driver: LedcTimerDriver<'_> = LedcTimerDriver::new(
        ledc.timer0, 
        &TimerConfig::default().frequency(2400.Hz().into()).resolution(esp_idf_hal::ledc::Resolution::Bits12)
    ).expect("Get LEDC timer.");

    let mut driver_0 = LedcDriver::new(ledc.channel0, &timer_driver, led_pin ).expect("Get LEDC driver.");
    println!("LED and LEDC is initialized.");

    
    println!("Initialize I2C bus...");
    let scl: AnyIOPin = peripherals.pins.gpio22.into();
    let sda: AnyIOPin = peripherals.pins.gpio23.into();
    let config = I2cConfig::new().baudrate(100.kHz().into()).scl_enable_pullup(false).sda_enable_pullup(false);
    let mut i2c = I2cDriver::new(peripherals.i2c0, sda, scl, &config)?;

    // Perform a quick bus scan. I currently can't put this into a method and/or call it 
    // at a later time, because... complicated. Let me explain:
    // - The scan needs the timeout parameter to work, which is not a 
    //   standard feature of the i2c trait, but an ESP-specific addition.
    // - To access multiple devices on the I2C bus, we need to wrap the bus 
    //   in a RefCell and then create a RefCellDevice for each driver.
    // - But RefCellDevice does not offer the timeout parameter
    // - So we make the scan on the raw i2c before wrapping it into RefCell
    for addr in 1..=127 {
        //info!(target: function_name!(), "Scanning Address {}", addr as u8);

        // Scan Address
        let res = i2c.read(addr as u8, &mut [0], 100);

        // Check and Print Result
        match res {
            Ok(_) => 
                println!("Address {}: found something!", addr as u8),
            Err(e) if e.code() == ESP_FAIL => 
                {}, // Usual error if nothing is present
            Err(e)
                => println!("Address {}: error: {}", addr as u8, e),
        }
    }

    let i2c_ref_cell = RefCell::new(i2c);
    println!("I2C bus is initialized.");


    println!("Initialize light sensor...");
    let mut light_sensor = AutoVeml6040::new(i2c_bus::RefCellDevice::new(&i2c_ref_cell))?;
    println!("Light sensor is initialized.");

    println!("Initialize temperature sensor...");
    let tmp1075_address = Address::from(77);
    let mut tempeature_sensor = Lm75::new(i2c_bus::RefCellDevice::new(&i2c_ref_cell), tmp1075_address);
    println!("Temperature sensor is initialized.");

    println!("Initialize power sensor...");
    //let ina_options = Opts::new(64, 100 * physic::MilliOhm, 1 * physic::Ampere);
    //let ina_options = Opts::default();
    let mut ina = INA219::new(i2c_bus::RefCellDevice::new(&i2c_ref_cell));
    ina.init(Calibration::Calibration_32V_2A).unwrap();
    println!("Power sensor is initialized.");

    println!("header; frequency; duty cycle; red; green; blue; white; temperature; voltage; current; power; efficiency");

    for frequency in (1_000..10_001).step_by(500) {
        let mut dc = 0;
        loop {
            if dc < 40 {
                dc += 1;
            } else if dc < 64 {
                dc += 2;
            } else if dc < 128 {
                dc += 4;
            } else if dc < 256 {
                dc += 8;
            } else if dc < 512 {
                dc += 16;
            } else if dc < 1024 {
                dc += 32;
            } else if dc < 2048 {
                dc += 64;
            } else {
                dc += 128;
            }

            if dc > 4095 {
                break;
            }

        

            timer_driver.set_frequency(Hertz(frequency as u32))?;
            driver_0.set_duty_cycle(dc)?;

            thread::sleep(Duration::from_millis(10));
        
            let mut sum_r = 0.0;
            let mut sum_g = 0.0;
            let mut sum_b = 0.0;
            let mut sum_w = 0.0;
            let mut sum_voltage = 0.0;
            let mut sum_current = 0.0;

            thread::sleep(Duration::from_millis(100));

            // The INA219 driver does not support multisampling, so I take many measurements and
            // average them on the ESP.
            // TODO use my own fork of the driver and enable multisampling.
            
            let mut light_count: f32 = 0.0;
            let mut power_count: f32 = 0.0;
            for i in 1..60 {
                if i < 10 {
                let result = light_sensor.read_absolute_retry();
                    if let Ok(measurement) = result {
                        sum_r += measurement.red;
                        sum_g += measurement.green;
                        sum_b += measurement.blue;
                        sum_w += measurement.white;
                        light_count += 1.0;
                    }
                    if i > 3 && light_count < 2.0 || i > 6 && light_count < 4.0 {
                        break;
                    }
                }
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

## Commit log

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2024-02-05 Replace unsafe code with synced access.
    [main.rs]
2024-02-09 Fix wifi configuration, fix swap between brightness and temperature, add switch for acces point vs. station mode.
    [main.rs]
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2024-02-18 Ready for production - but needs expensive hole plating.
    [LED_Module_A.kicad_pcb, LED_Module_A.kicad_sch]
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2024-02-18 New layout with angled SMD header, but probably not aligned correctly.
    [LED_Module_A.kicad_pcb, LED_Module_A.kicad_sch]
2024-02-18 And yet another connector. This one should be perfect!
    [LED_Module_A.kicad_pcb, LED_Module_A.kicad_sch]
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2024-02-19 Exchange out-of-stock LEDs by alternatives, clean up parts table.
    [LED_Module_A.kicad_pcb, LED_Module_A.kicad_sch]
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2024-02-23 Not working: implement light sensor manually.
    [main.rs]
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2024-02-25 SNTP service, configurable time zone and Ds18b20 error handling.
    [main.rs]
2024-02-26 Better error handling for the light sensor reading.
    [main.rs]
2024-03-02 Add LED module A2, an improved two-layer variant of module A.
    [LED_Module_A.kicad_pcb, LED_Module_A.kicad_sch]
2024-03-02 Add LED Test Module, where you can solder a single SMD LED of just about any size, and matching resistor(s).
    [LED_Test_Module.kicad_pcb, LED_Test_Module.kicad_sch]
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2024-03-05 Remove trailing whitespace, hoping to fix git this way.
    [main.rs]
2024-03-05 Add LED Module B (very early tests, likely to be redone from scratch)
    [LED_Module_B-rounded.kicad_pcb, LED_Module_B.kicad_pcb, LED_Module_B.kicad_sch]
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2024-03-07 Implement OTA (Over the Air) Updates. This is rather hacky, but it actually works.
    [partitions.csv]
2024-03-14 Add test program for the tlc59711 LED controller / driver.
    [partitions.csv]
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2024-03-15 More logging for the presence sensor, especially in case it does not work.
    [main.rs, presence.rs]
2024-03-16 Finally fix that flickering in set_color, which also affected set_temperature_and_brightness.
    [pwm.rs]
2024-03-18 Minor changes to the Kicad files (as clarification for PCBWay for their quality assurance).
    [LED_Module_A.kicad_pcb, LED_Module_A.kicad_sch, LED_Module_A2.kicad_pcb]
2024-03-18 Added test points and a lot more silkscreen.
    [LED_Module_A.kicad_pcb]
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2024-03-25 Minor changes in KiCad files (might be cause by updating from KiCad 7 to 8).
    [JLCPCB.kicad_pcb]
2024-03-25 Add LED Module C and update many READMEs superficially.
    [LED_Module_C.kicad_pcb, LED_Module_C.kicad_sch]
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2024-04-14 Add the first LED Driver board and a template for future boards (which might already be outdated).
    [Driver Module A.kicad_pcb, Driver Module A.kicad_sch, Driver Module X.kicad_pcb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]
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2024-04-15 Many small fixes and cleanups to make this project compile and run again, including upgraded rust version, using the new wrapper in the VEML driver (which worked in another project, but now does not 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
    [leds.rs, light_sensor.rs, main.rs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]
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2024-04-23 v2 of the adaptor, which now should really fit into the enclosure.
    [LED_Module_A_Adaptor.kicad_pcb, LED_Module_A_Adaptor.kicad_sch]
2024-04-23 Minor silkscreen improvements on the driver module A
    [Driver Module A.kicad_pcb, Driver Module A.kicad_sch]
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2024-06-17 Finally upload the (very bad) LED Module D.
    [LED_Module_D.kicad_pcb, LED_Module_D.kicad_sch]
2024-07-03 Several changes to LED modules A2 and C, two items added to the library. Readme updated.
    [LED_Module_A.kicad_sch, LED_Module_A2.kicad_sch, LED_Module_C.kicad_pcb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]
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2024-07-03 Fix / add meta data in title_block for all LED modules.
    [LED_Module_A_Adaptor.kicad_pcb, LED_Module_A_Adaptor.kicad_sch, LED_Module_B.kicad_pcb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]
2024-07-04 Add the adaptor for LED module E and adjust README files.
    [LED_Module_E_Adaptor.kicad_pcb, LED_Module_E_Adaptor.kicad_sch]
2024-07-04 Upgrade LED module E adaptor to v1.1 with improved GND return path.
    [LED_Module_E_Adaptor.kicad_pcb, LED_Module_E_Adaptor.kicad_sch]
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2024-09-15 Complete redesign of LED Module E for the ABL.
    [LED_Module_E.kicad_pcb, LED_Module_E.kicad_sch]
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2024-09-15 Mirror the connector, optimize VLED between connector and LEDs.
    [LED_Module_E.kicad_pcb, LED_Module_E.kicad_sch, LED_Module_E.step]
2024-09-23 Latest versions of all five PCBs that make up the ABL, maybe ready for prototype production.
    [Conductor.kicad_pcb, Conductor.kicad_sch, Controller.kicad_pcb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]
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2024-09-24 Clean up schematics and minor fixes in PCB layouts.
    [Conductor.kicad_pcb, Conductor.kicad_sch, Controller.kicad_pcb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]
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2024-09-29 Add Mosfets to power down presence sensory individually.
    [Controller.kicad_pcb, Controller.kicad_sch, Controller.step]
2024-09-29 Add "make first, break last" contacts to prevent latch-up when hot-plugging.
    [Conductor.kicad_pcb, Conductor.step]
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2024-09-29 Enlarged PCB at the top to add protective earth connector, optimized traces and I2C return paths.
    [power.kicad_pcb, power.kicad_sch]
2024-09-30 Revert board size, swap some mounting holes and protective earth, fix swapped N and L wires.
    [power.kicad_pcb, power.kicad_sch]
2024-09-30 Move light sensor closer to the center, many microoptimizazions.
    [Controller.kicad_pcb, Controller.step]
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2024-10-01 Metadata and minor cleanup, documentation and typo fix.
    [Controller.kicad_pcb, Controller.kicad_sch, power.kicad_pcb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]
2024-10-01 Controller: Swivel GPIOs 16, 21, 22, 25 to be compatible with all three feather variants and add README.
    [Controller.kicad_pcb, Controller.kicad_sch]
2024-10-01 Rename files, names and labels to be more consistent. Add READMEs for connectors and extend some other READMEs.
    [Conductor.step, Controller.step, controller.kicad_pcb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]
2024-10-01 Move LED Module E to the ABL directory and update all affected READMEs.
    [LED_Module_E.kicad_pcb, LED_Module_E.kicad_sch, LED_Module_E.step]
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2024-10-16 Implemented a lot of recommended changes, including layer swap.
    [LED_Module_E.kicad_pcb, LED_Module_E.kicad_sch]
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2024-10-18 Add own / optimized footprints (bigger pads), add fuse and current limiting to the power module.
    [power.kicad_pcb, power.kicad_sch]
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2024-10-18 Fixed a few footprints and part numbers.
    [LED_Module_E.kicad_pcb, LED_Module_E.kicad_sch]
2024-10-18 Fix DRC errors and do some finishing touches.
    [LED_Module_E.kicad_pcb]
2024-10-18 Adjusted pin assignment of i1 to i4, rotated the flex connector, and rerouted most of the long traces.
    [controller.kicad_pcb, controller.kicad_sch]
2024-10-18 Finally added the missing schottky diode and re-layoutet the power area.
    [controller.kicad_pcb, controller.kicad_sch]
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2024-10-19 Make controller PCB ready for prototype prodution: change level shifter, re-route many traces, etc.
    [controller.kicad_pcb, controller.kicad_sch]
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2024-10-28 Fix orientation of Stemma QT / Quiic socket, add test points for voltages.
    [controller.kicad_pcb, controller.kicad_sch]
2024-10-29 Fix 5V power supply for Feather.
    [controller.kicad_pcb, controller.kicad_sch]
2024-10-29 Change pins 13 and 16 to fix bootloader problem. Nees better docu.
    [controller.kicad_pcb, controller.kicad_sch]
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2024-11-01 Create custom clearance rules and fix most DRC errors.
    [controller.kicad_pcb]
2024-11-01 Increase clearance of 230V nets to 3.175 mm, the maximum that is attainable with WAGO connerctors anyway.
    [power.kicad_pcb, power.kicad_sch]
2024-11-01 Added an EEPROM to the power module and changed the EEPROM on the LED module to be individually addressable.
    [LED_Module_E.kicad_pcb, LED_Module_E.kicad_sch, power.kicad_pcb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]
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2024-11-10 Fix reversed labeling of testpoints for mosfet inputs.
    [LED_Module_E.kicad_pcb]
2024-11-10 Fix orientation of the flex connector.
    [LED_Module_E.kicad_pcb, LED_Module_E.kicad_sch]
2024-11-10 Move LED and let it shine brighter, extend outline, many small enhancements.
    [power.kicad_pcb, power.kicad_sch]
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2024-11-12 Several small fixes
    [LED_Module_E.kicad_sch, LED_Module_E_ Castellation_Test.kicad_pcb, LED_Module_E_copper.kicad_pcb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]
2024-11-12 Greatly increase clearance for 230V tracks. Chosen 30W power supply and removed option for 20W. Many other small improvements.
    [power.kicad_pcb, power.kicad_sch]
2024-11-14 Extended with wings to attach presence sensors directly. Removed distinction between VLED and 5V. Much cleanup.
    [controller.kicad_pcb, controller.kicad_sch]
2024-11-15 Many, many minor updates to the big PCBs, and a few simple helper PCBs.
    [Feather_Ground.kicad_pcb, LED_Module_E.kicad_pcb, LED_Module_E.kicad_sch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]
2024-11-15 Fix missing ground collection - this PCB had *one* job!
    [Feather_Ground.kicad_pcb]
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2024-11-28 Add missing LCSC part numbers and bump version / date.
    [LED_Module_E.kicad_pcb, LED_Module_E.kicad_sch, LED_Module_E_copper.kicad_pcb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]
2024-12-11 Starting to port Adafruit ESP32-C6 Feather - STEMMA QT PCB from EagleCAD to KiCad.
    [Adafruit Feather ESP32-C6.kicad_pcb, Adafruit Feather ESP32-C6.kicad_sch]
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2024-12-12 Put BOM into the README because the CSV preview on Github does not work.
2024-12-12 Replace BOM table with actual BOM table.
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2024-12-22 Move capacitor to avoid collision with power box enclosure.
    [power.kicad_pcb, power.kicad_sch]
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
